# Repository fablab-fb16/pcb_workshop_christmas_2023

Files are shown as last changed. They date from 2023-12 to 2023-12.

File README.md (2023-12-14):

# Blinky Christmas Tree Ball - Soldering Kit

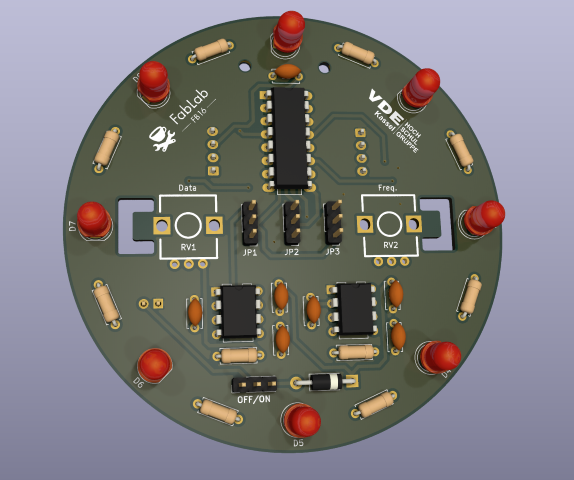
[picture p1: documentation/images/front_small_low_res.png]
PCB Front Side


Designed by Stefan Kablowski, Max Lindemann, Janos Föth.

Soldering workshop kindly sponsored by VDE Bezirksverein Kassel e. V.

## Quick Links

- [Detailed Build Instructions (EN)](/documentation/Build%20Instructions.md) / [Detaillierte Bauanleitung (DE)](/documentation/Build%20Instructions%20DE.md)
- [Assembly List](/documentation/Assembly%20List.md)
- [Usage Instructions](/documentation/Usage%20Instructions.md)
- [Schematics](/documentation/schematics.md)
- [Interactive BOM](https://fablab-fb16.github.io/pcb_workshop_christmas_2023/)

## Features
- Interactive: Adjustable blinking pattern and speed via two potentiometers
- Daisy-Chaining possible: Connect multiple christmas balls and push signals from master down the line for various patterns

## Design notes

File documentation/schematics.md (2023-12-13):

# Schematics

Two timers generate a square-wave signal (freqency independatly variable by potentiometers, see /notebooks folder for Jupyter notebook on frequency range calculation).

These two signals are used on data and clock input of shift register to create output patterns. Each output of the shift register is connected to one LED.

The Jumpers are used to select signal source and output source for daisy-chaining multiple boards. See [Usage Instructions](/documentation/Usage%20Instructions.md) for more info on this.

## Main Circuit
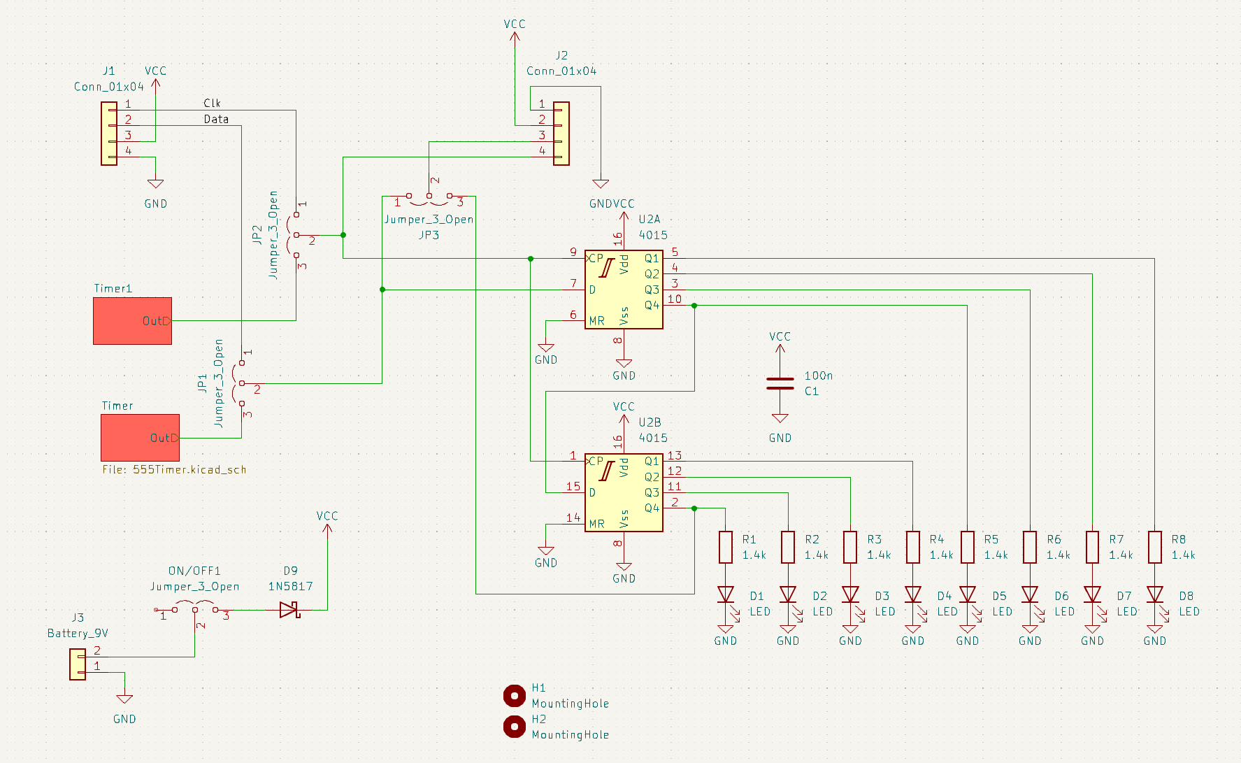
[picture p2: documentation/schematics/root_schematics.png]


## Timer (Data)
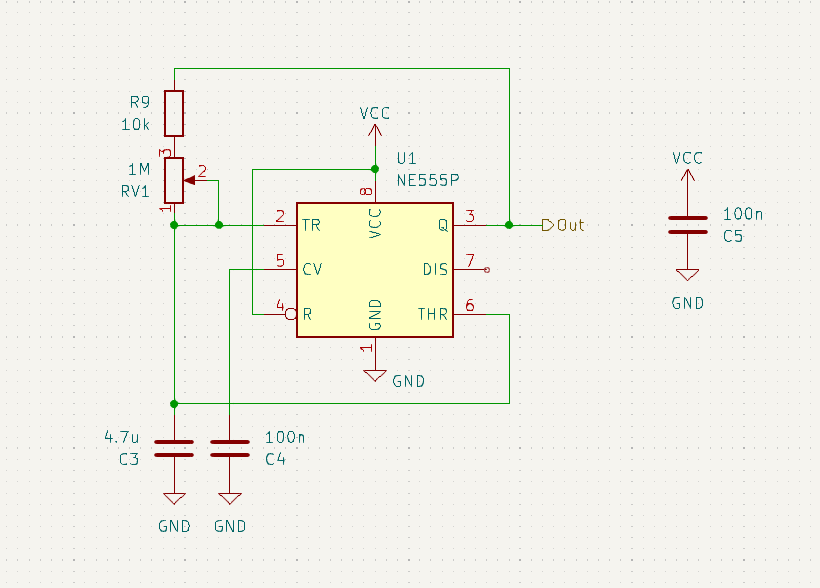
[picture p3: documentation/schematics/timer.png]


## Timer1 (Clock)
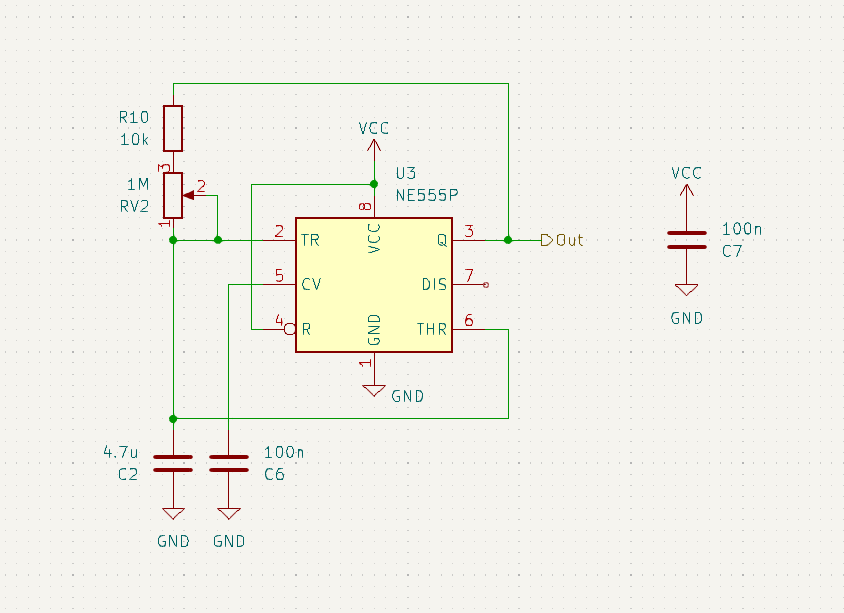
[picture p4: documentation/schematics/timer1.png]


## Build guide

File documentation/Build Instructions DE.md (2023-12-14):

# Bauanleitung (DE)

Dies ist eine detaillierte Anleitung mit Bildern. tl;dr -> [Assembly List](/documentation/Assembly%20List.md)

English Version: [Build Instructions](/documentation/Build%20Instructions.md)

## Allgemeine Infos
- Wenn du noch nie gelötet hast, schau dir die Anleitung an (auf Englisch, mit Bildern): [How to solder](/documentation/How%20to%20Solder.md)
- Alle Komponenten werden auf der Seite der Platine platziert, auf der die zugehörige Markierung des Bauteils ist. Gelötet wird immer auf der jeweils anderen Seite der Platine.
- Alle Bauteile haben eine Bezeichnung, welche in der Anleitung genannt wird, z.B. "R1" oder "D9". Diese Bezeichnung ist auch auf der Platine aufgedruckt. Dort muss das jeweilige Bauteil platziert werden.
- Manche Bauteile haben eine Orientierung -> Es ist wichtig, dass sie richtigherum eingebaut werden. Dies ist in der Anleitung in rot mit "Caution" gekennzeichnet. Einbaurichtung vor dem Löten nochmal prüfen. 
- Falls du Fragen hast: Am besten **vor** dem Löten fragen. 😉
- Have fun. 👩‍🏭👨‍🏭

## Anleitung
### Übersicht
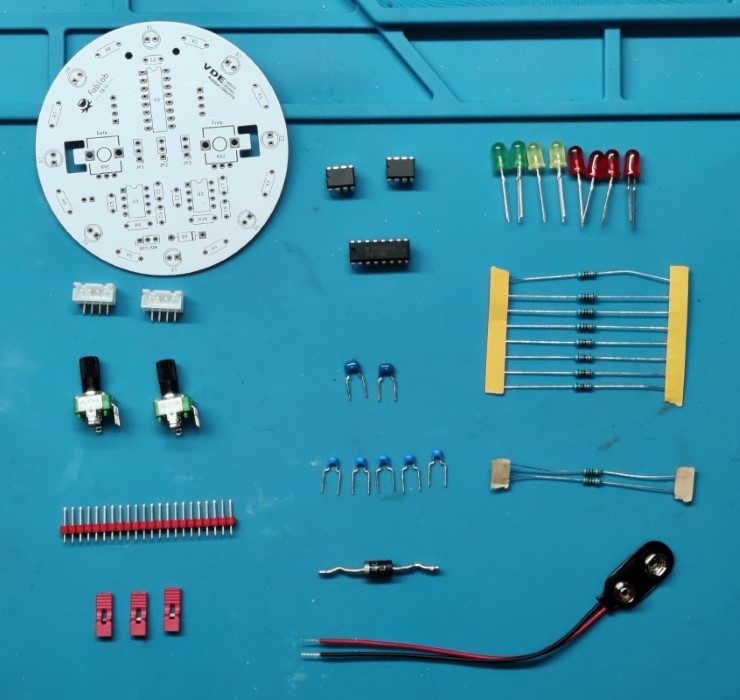
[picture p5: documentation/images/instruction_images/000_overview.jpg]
Overview

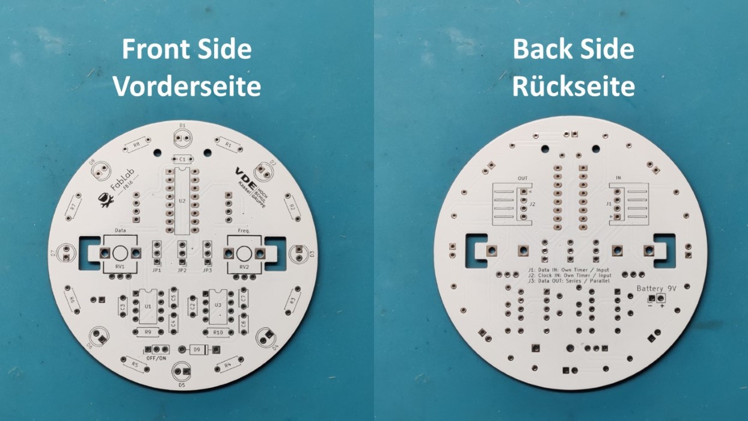
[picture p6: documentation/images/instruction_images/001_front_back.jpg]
Front-Back


### Erstes Bauteil - Diode: D9
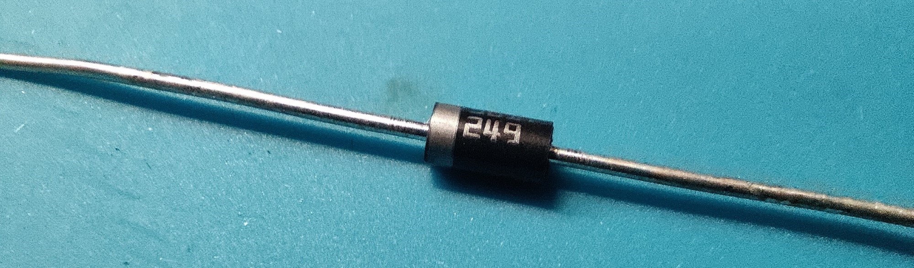
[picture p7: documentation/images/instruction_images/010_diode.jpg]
Diode


Biege die Beine der Diode (U-förmig)
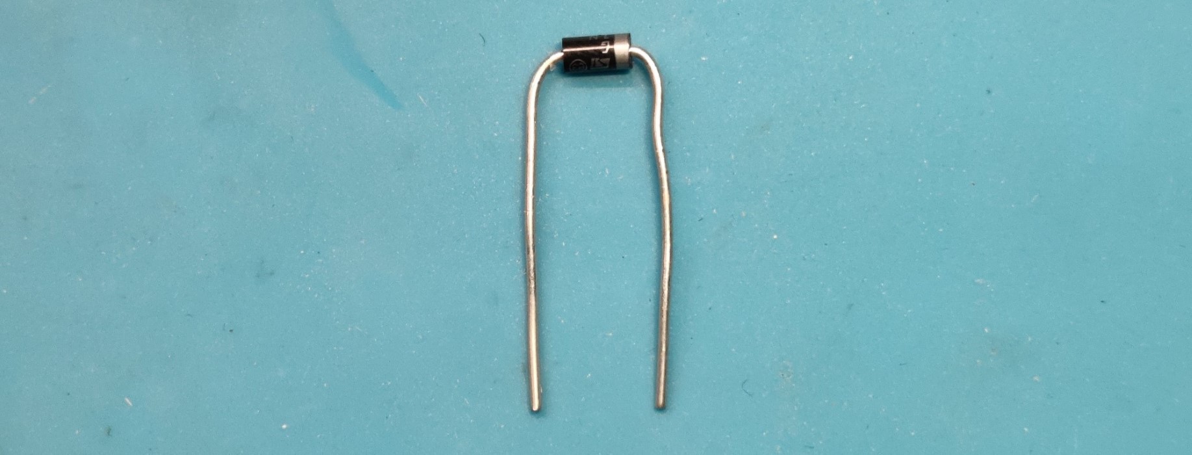
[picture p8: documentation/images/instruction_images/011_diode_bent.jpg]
Diode Bent


Stecke sie auf die Platine an der Position D9 (s. Bild unten).
> [!Caution]
> Beachte die Einbaurichtung: Silberner Ring nach rechts, wie auf der Platine markiert.

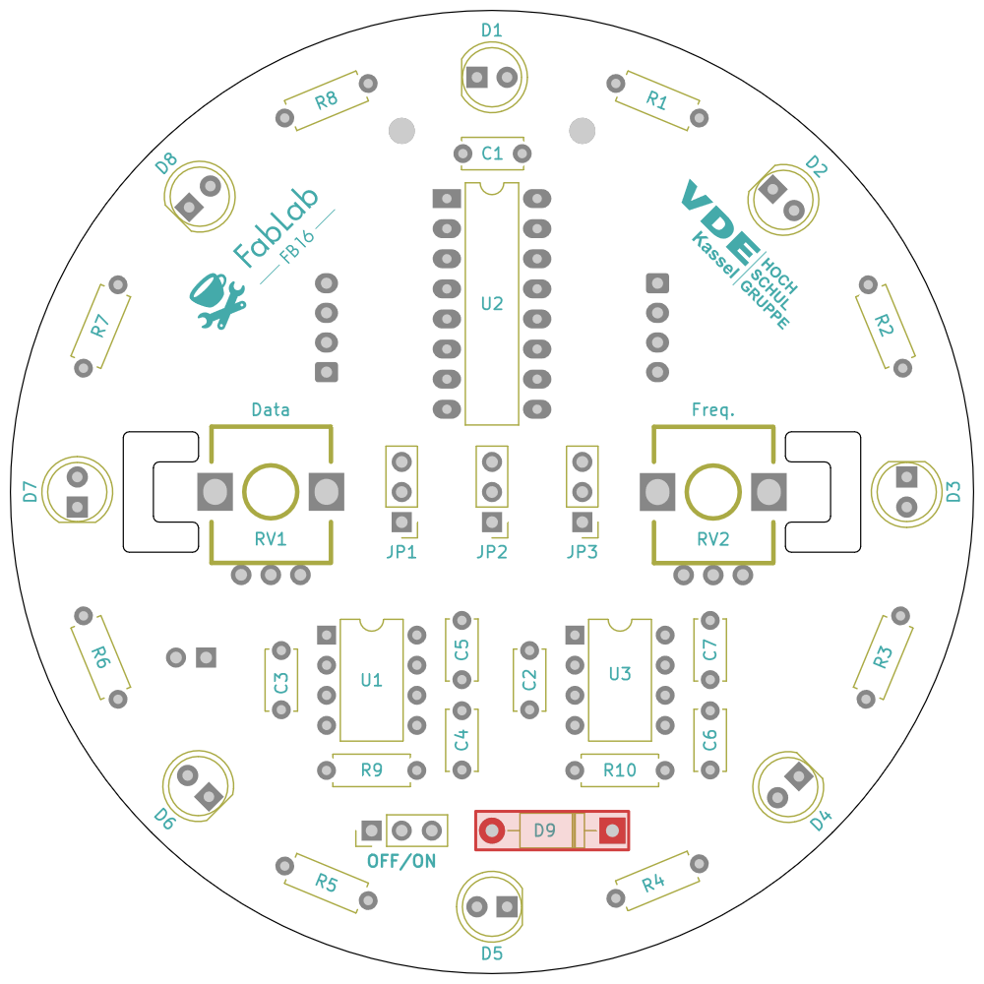
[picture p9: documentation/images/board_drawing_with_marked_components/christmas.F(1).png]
Diode on Board Drawing


Stecke die Diode bis ganz auf die Platine. Drehe die Platine um und löte die beiden Kontakte.
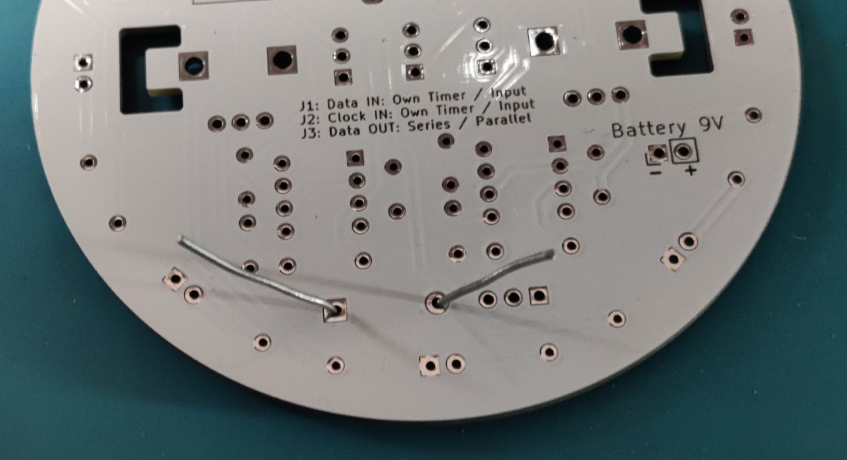
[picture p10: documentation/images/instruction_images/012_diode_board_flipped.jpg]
Diode Board Flipped

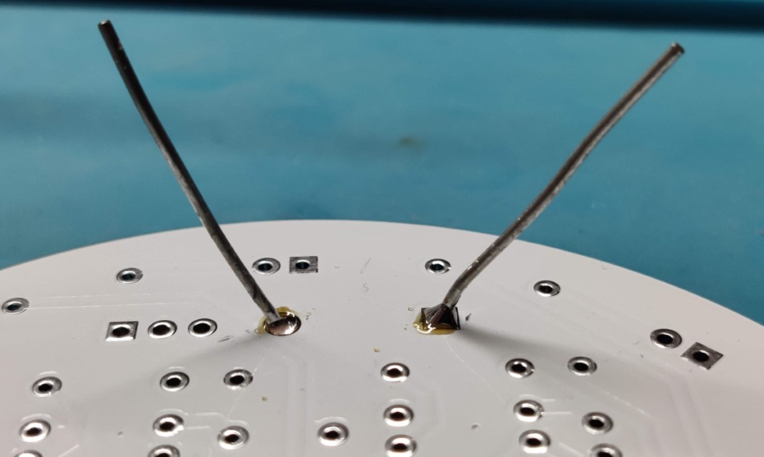
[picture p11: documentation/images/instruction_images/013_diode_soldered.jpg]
Diode Soldered


Schneide die Beine **oberhalb** der Lötstellen ab (nicht die Lötstelle selbst abschneiden).
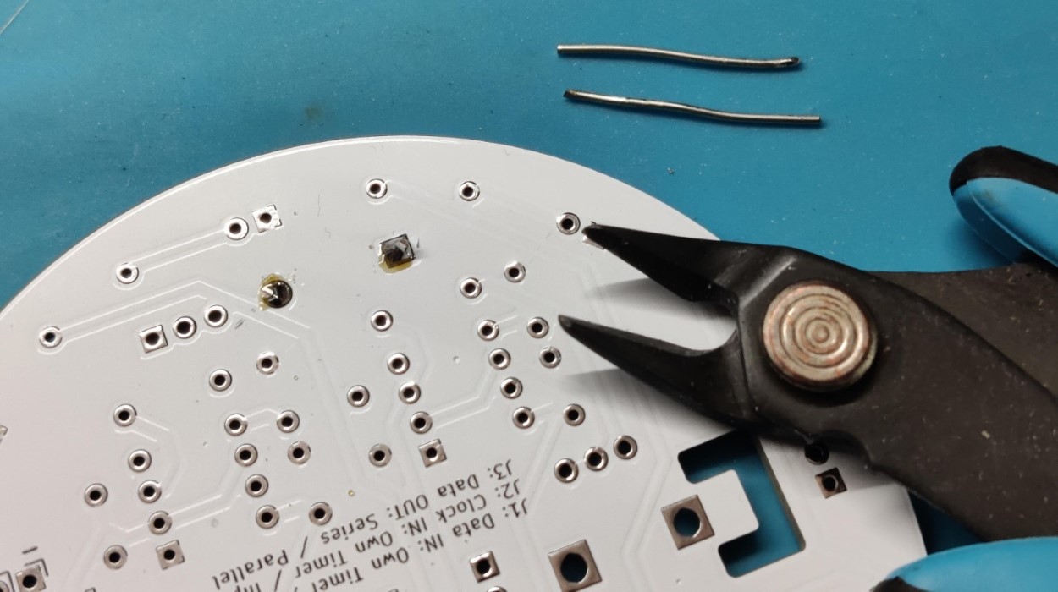
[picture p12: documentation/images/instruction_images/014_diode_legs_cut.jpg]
Diode Legs cut

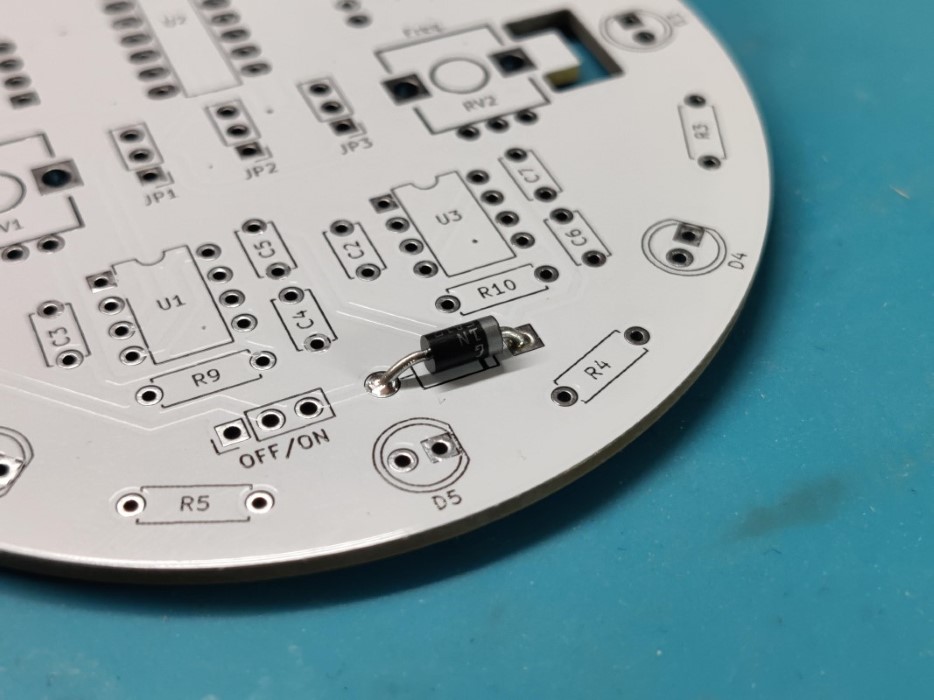
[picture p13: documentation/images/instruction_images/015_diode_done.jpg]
Diode Done


Erstes Bauteil geschafft.

### Widerstände: R1, R2, R3, R4, R5, R6, R7, R8
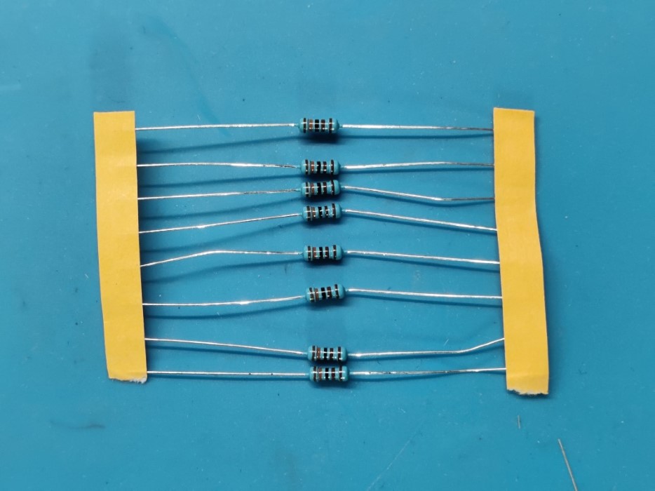
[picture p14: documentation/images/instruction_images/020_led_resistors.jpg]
LED Resistors 8x 1.3k

Identifiziere die Widerstände an ihren Farbringen: braun - orange - schwarz - braun - braun (Wert: 1.3k)

Biege die Beine (U-förmig), wie bei der Diode.

Stecke sie auf die Platine (diesmal ist die Einbaurichtung egal).
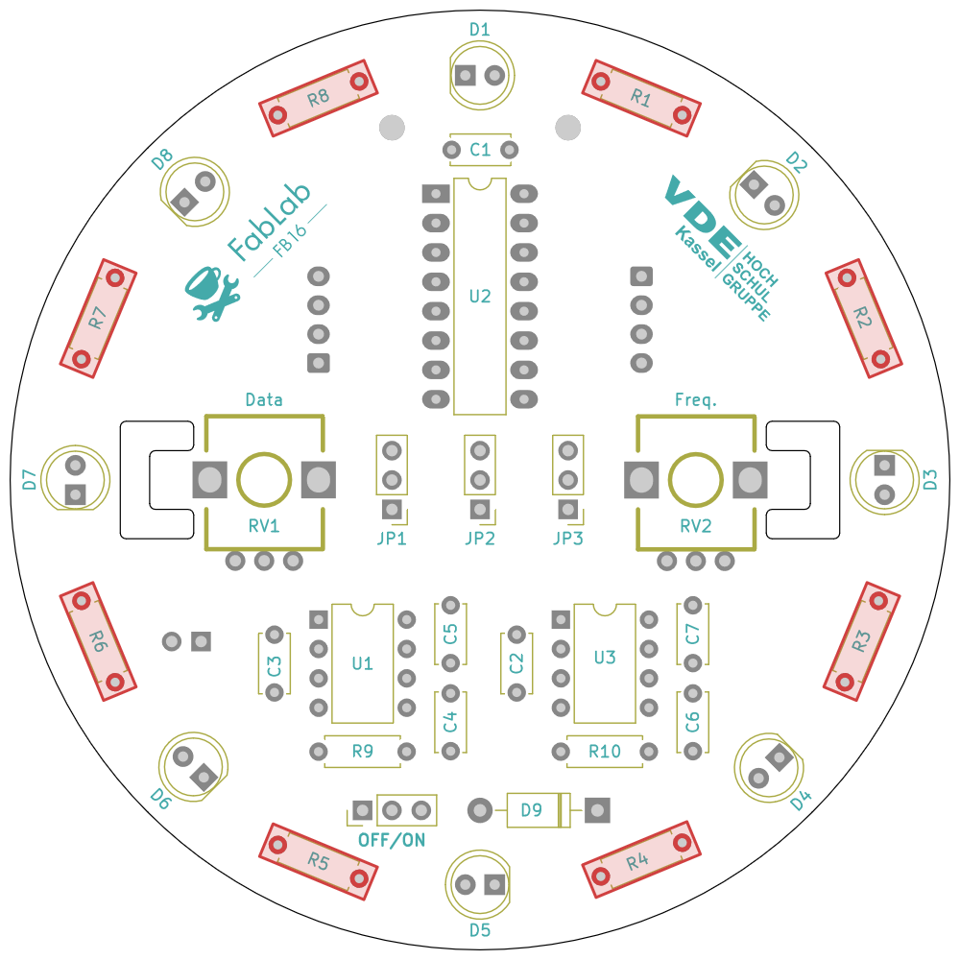
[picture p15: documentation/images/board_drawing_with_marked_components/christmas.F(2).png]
LED Resistors Board Drawing


Löten, Beine abschneiden, wiederholen bis alle Widerstände aufgelötet sind.

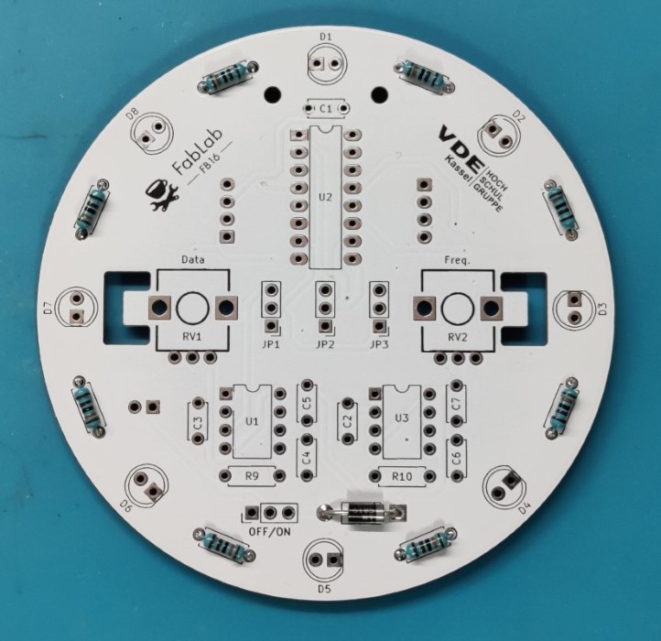
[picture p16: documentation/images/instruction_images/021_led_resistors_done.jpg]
LED Resistors Done


### Widerstände: R9, R10
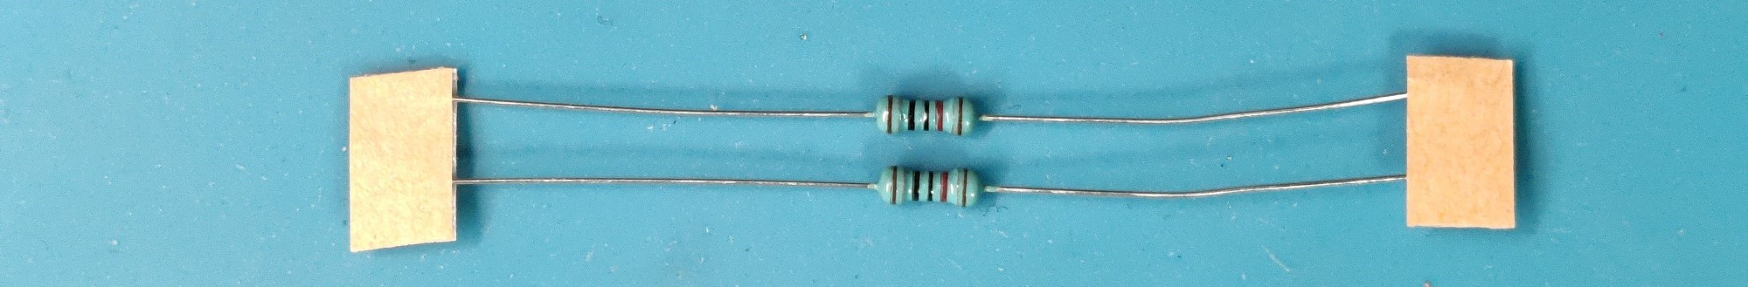
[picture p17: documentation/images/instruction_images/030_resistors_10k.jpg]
Resistors 2x 10k

Identifiziere die Widerstände an ihren Farbringen: braun - schwarz - schwarz - rot - braun (Wert: 10k)

Beine biegen, auf Platine stecken, löten, Beine abschneiden, wiederholen.
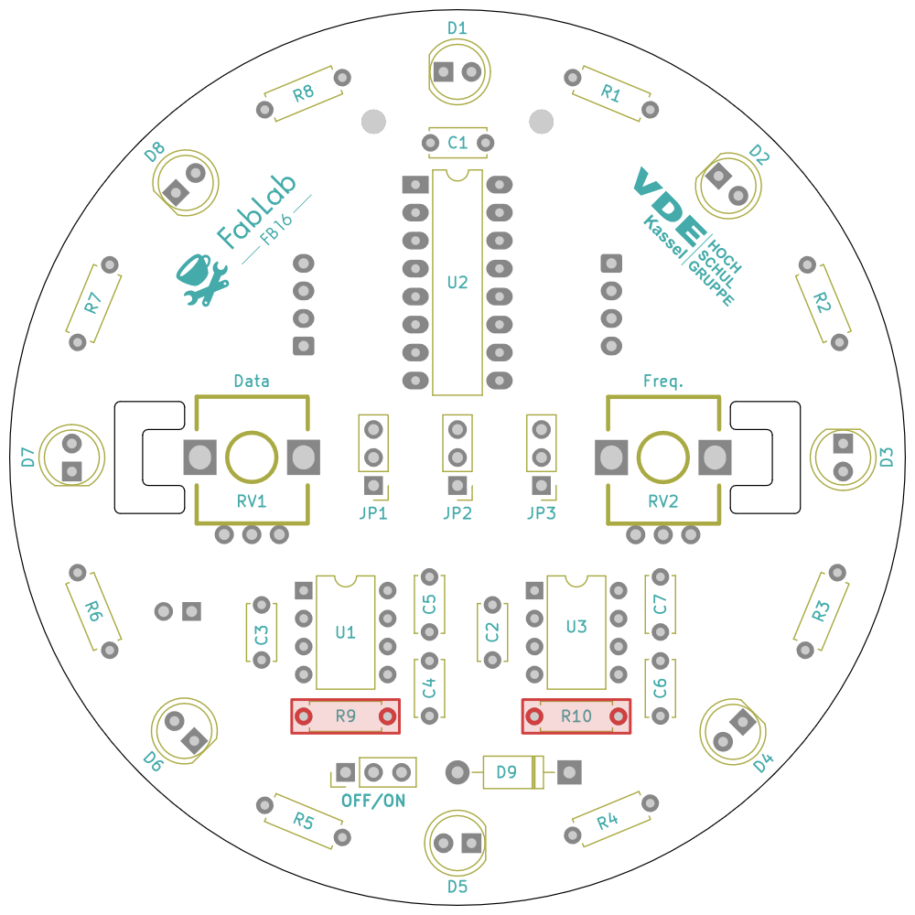
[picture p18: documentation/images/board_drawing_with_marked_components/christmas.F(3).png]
Resistors Board Drawing

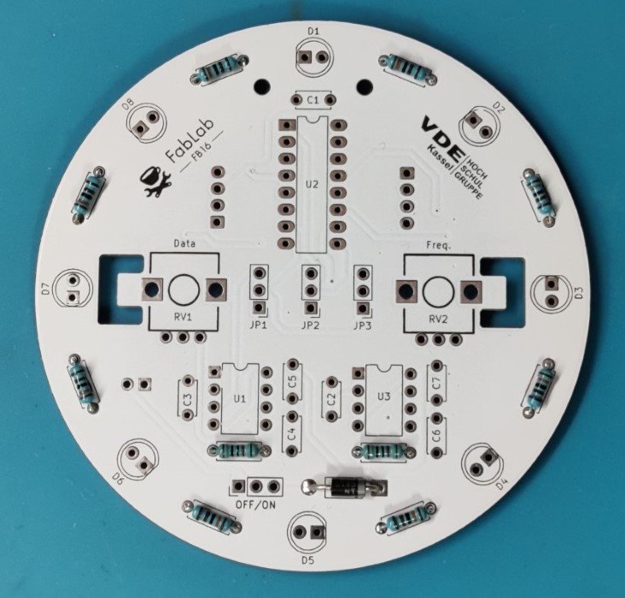
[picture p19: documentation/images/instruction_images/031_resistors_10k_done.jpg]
Resistors 2x 10k done


### Timer: U1, U3
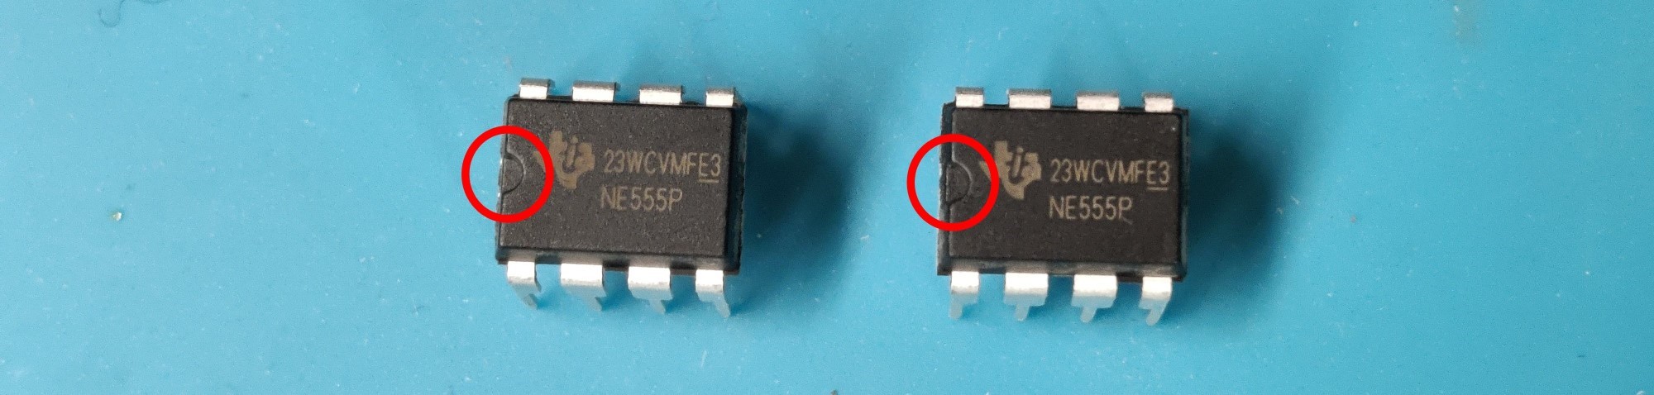
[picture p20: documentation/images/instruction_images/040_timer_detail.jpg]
Timers Detail

> [!Caution]
> Beachte die Einbaurichtung! Kleine Einkerbung nach oben.

Aufstecken, alle Beinchen löten. Verfahre mit allen weiteren Bauteilen so.

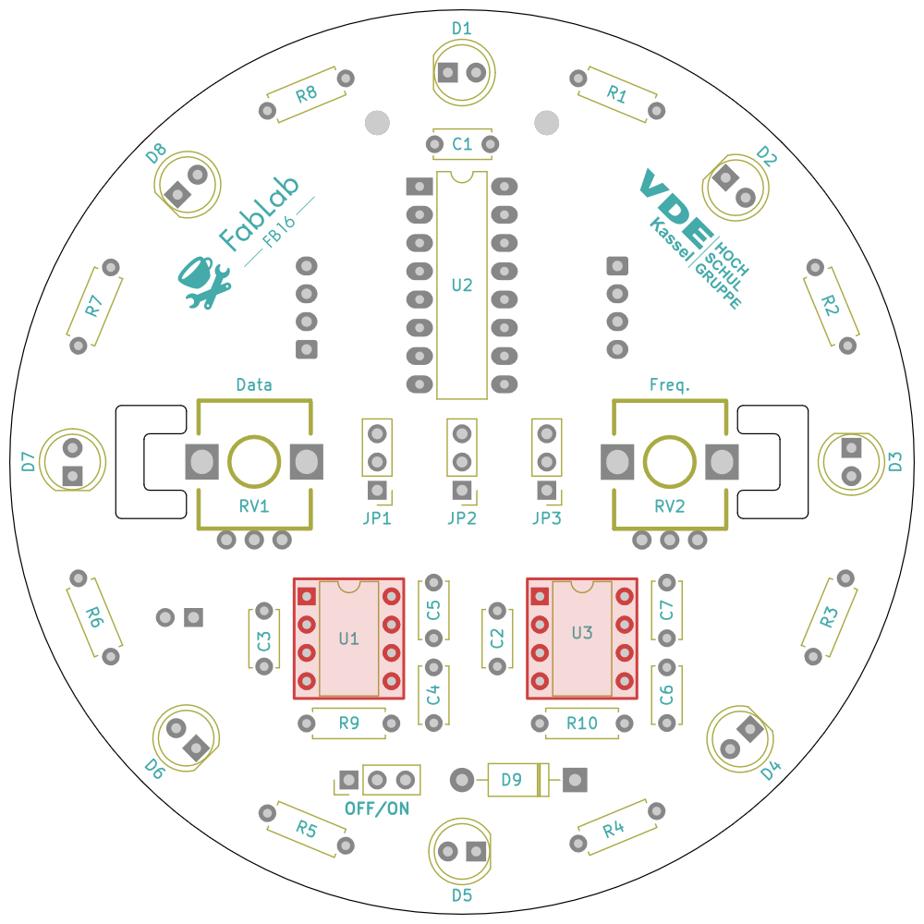
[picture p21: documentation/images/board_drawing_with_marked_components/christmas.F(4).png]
Timers Board Drawing

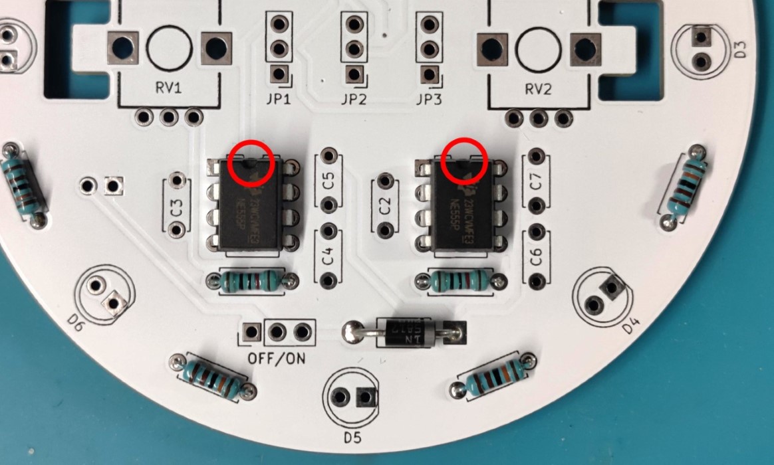
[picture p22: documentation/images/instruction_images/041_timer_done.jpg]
Timers done


### Schieberegister: U2
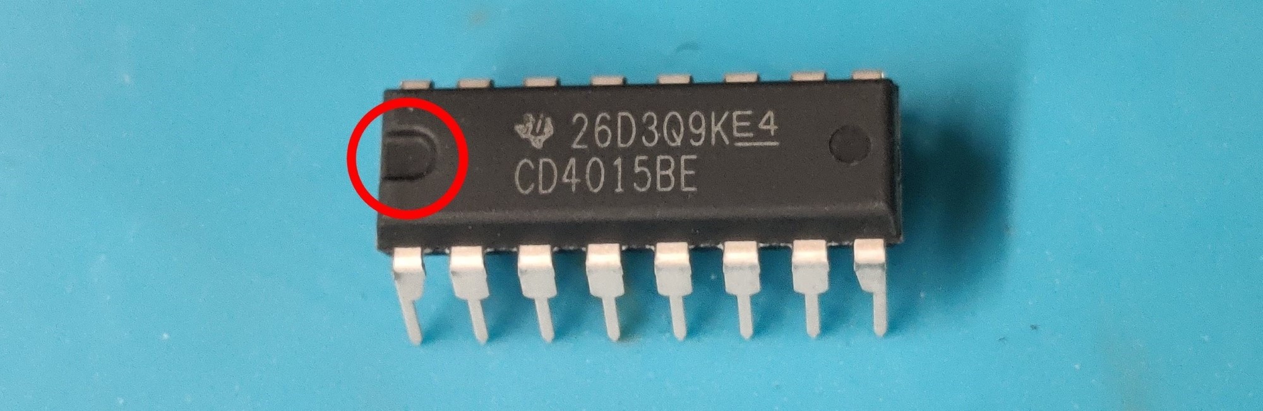
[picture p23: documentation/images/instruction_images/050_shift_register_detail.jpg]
Shift register Detail

> [!Caution]
> Beachte die Einbaurichtung! Kleine Einkerbung nach oben.

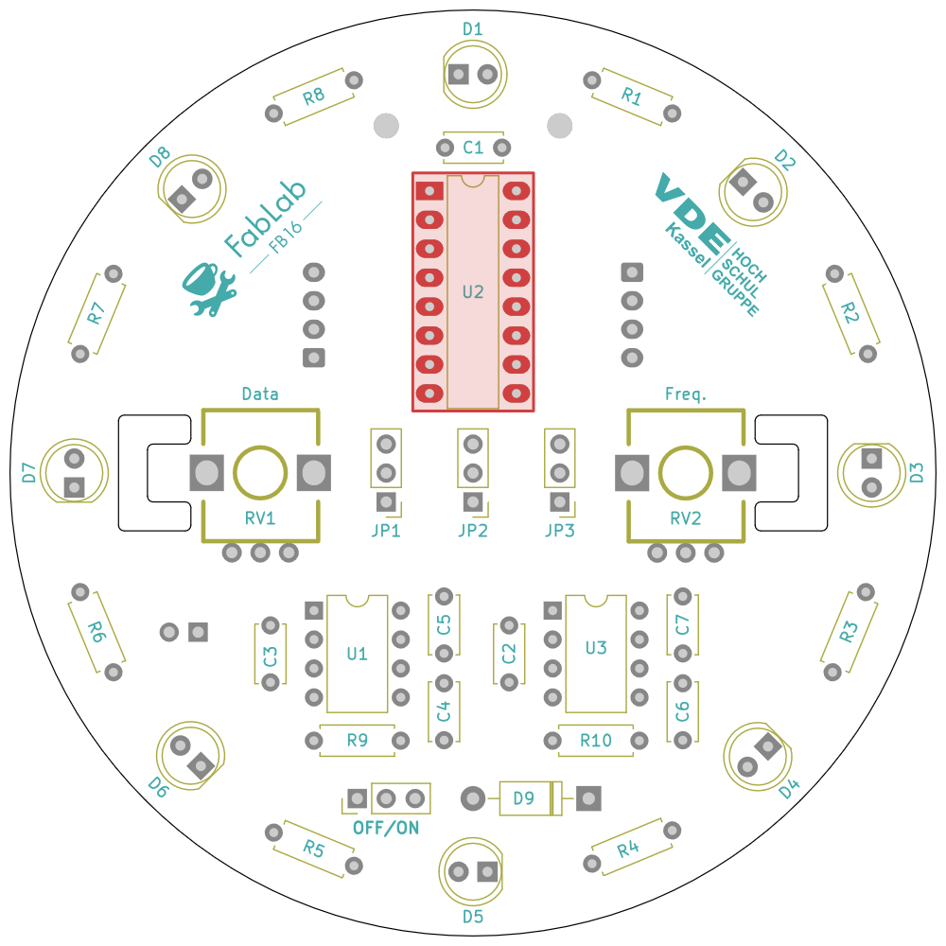
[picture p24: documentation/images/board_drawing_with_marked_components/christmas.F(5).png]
Shift register Board Drawing

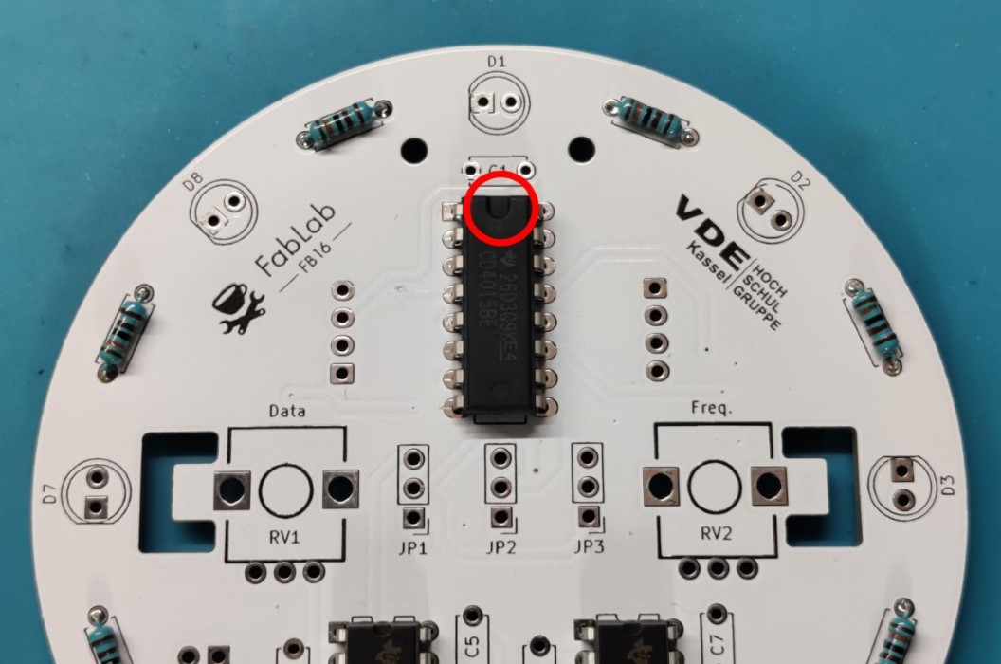
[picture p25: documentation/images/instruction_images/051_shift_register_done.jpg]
Shift register done


### Kondensatoren: C1, C4, C5, C6, C7
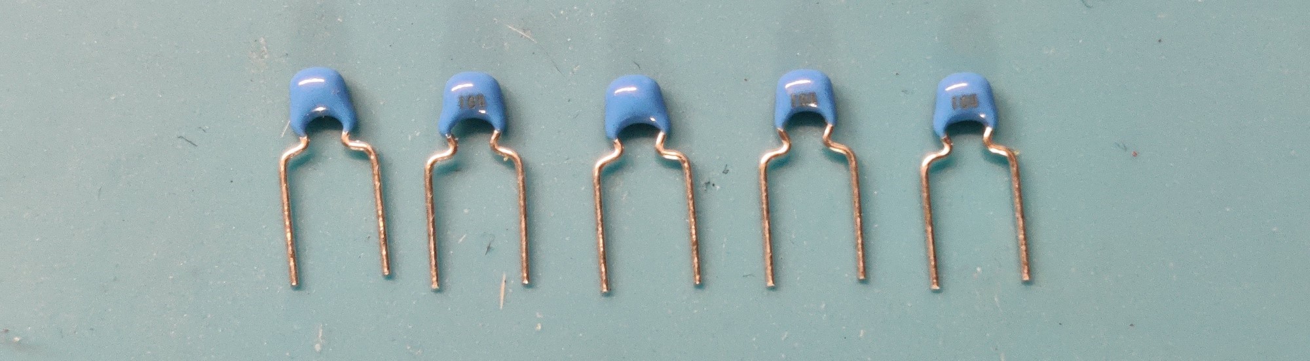
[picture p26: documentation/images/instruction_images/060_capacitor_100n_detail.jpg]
Capacitors 100nF Detail


> [!Caution]
> Achtung, es gibt Verschiedene! Hier brauchst du die Kleineren mit dem Aufdruck "104" (Wert: 100nF).

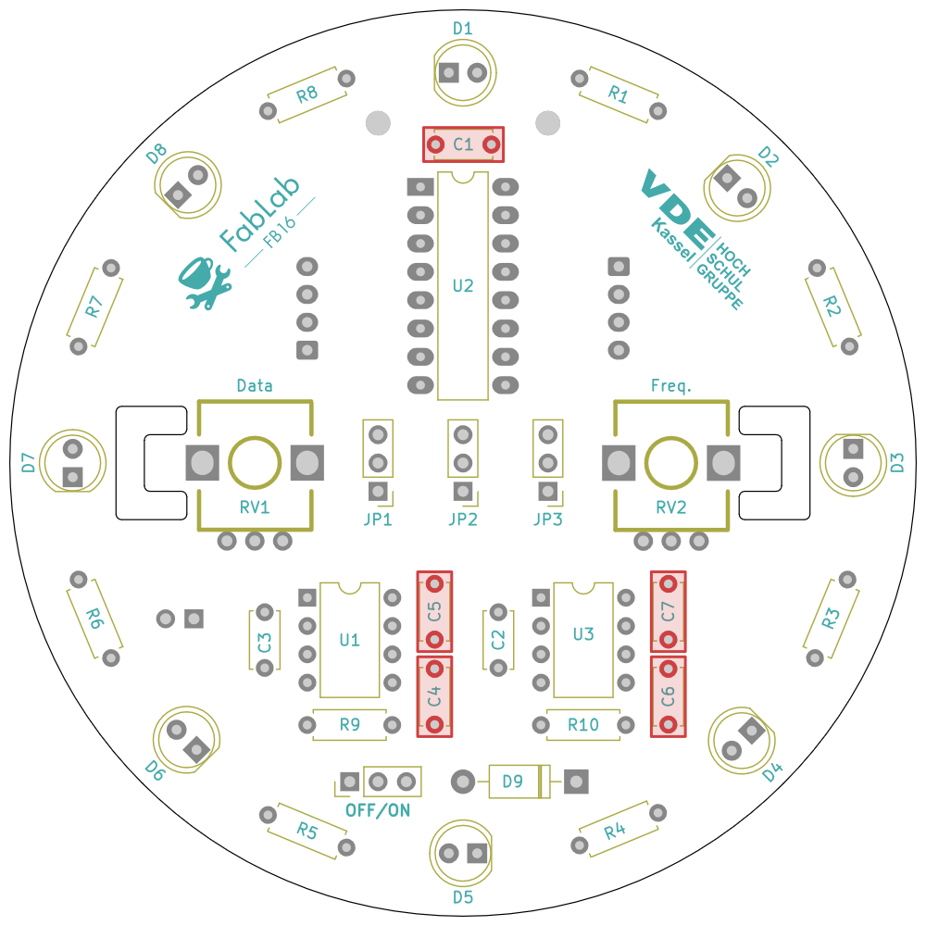
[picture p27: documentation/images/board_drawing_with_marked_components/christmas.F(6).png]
Capacitors 100nF Board Drawing

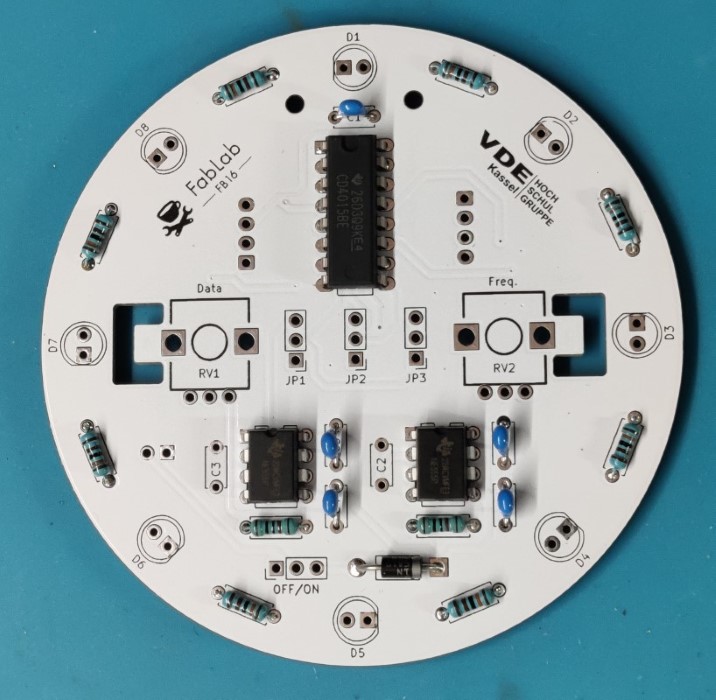
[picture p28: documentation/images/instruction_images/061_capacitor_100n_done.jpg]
Capacitors 100nF done


### Kondensatoren: C2, C3
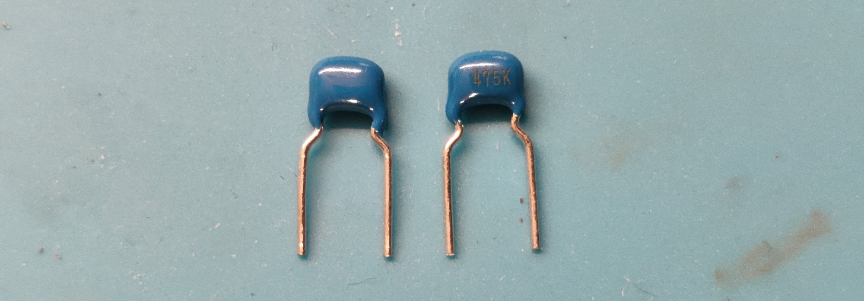
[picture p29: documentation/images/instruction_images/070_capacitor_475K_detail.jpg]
Capacitors 4.7uF Detail


> [!Caution]
> Achtung, es gibt Verschiedene! Hier brauchst du die Größeren mit dem Aufdruck "475K" (Wert: 4.7uF).

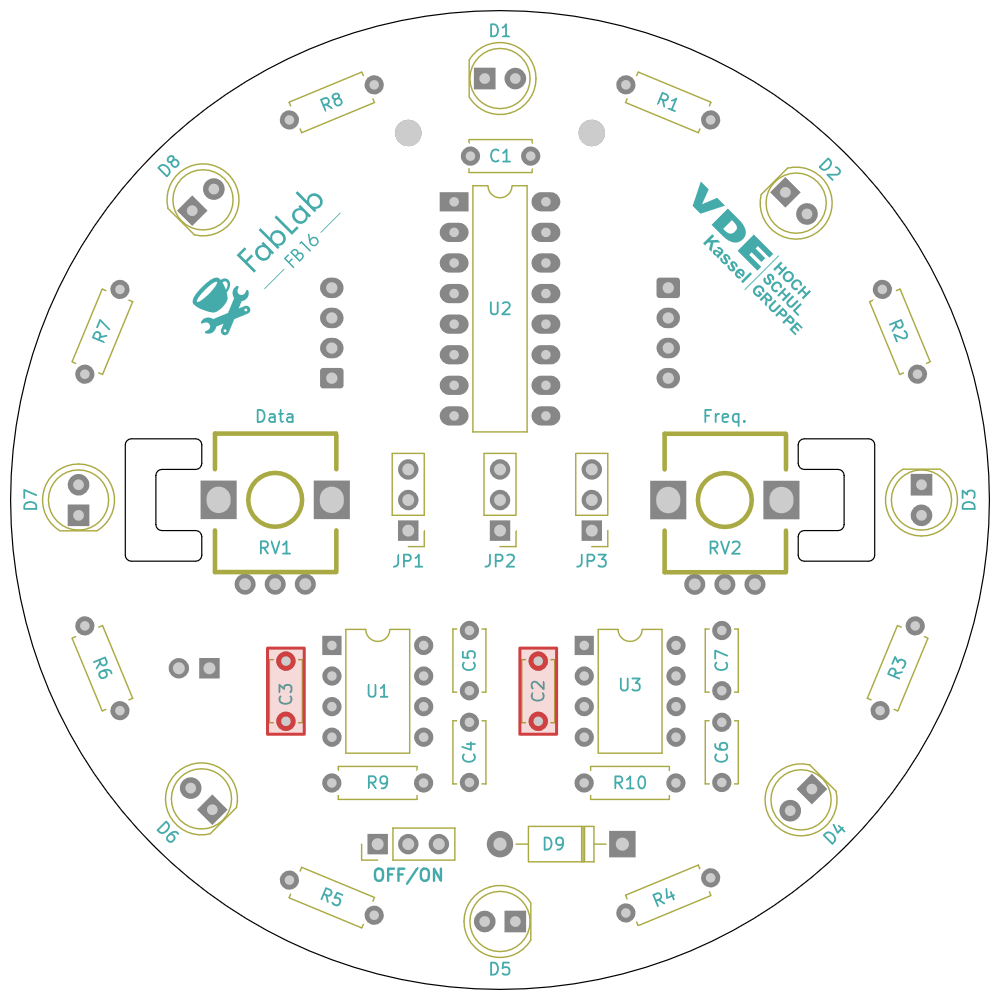
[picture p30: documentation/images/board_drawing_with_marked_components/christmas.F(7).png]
Capacitors 4.7uF Board Drawing

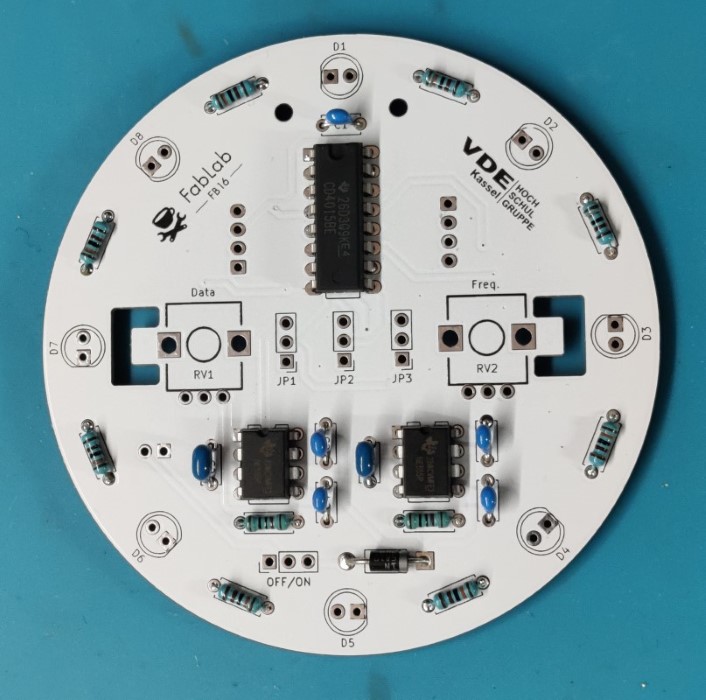
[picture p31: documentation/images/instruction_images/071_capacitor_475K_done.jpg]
Capacitors 4.7uF done


### LEDs: D1, D2, D3, D4, D5, D6, D7, D8
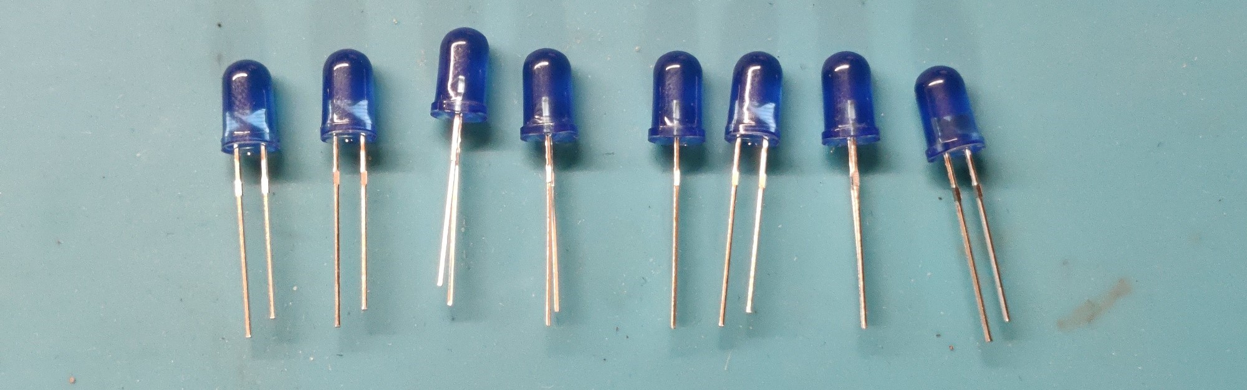
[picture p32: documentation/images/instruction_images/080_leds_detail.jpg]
LEDs Detail

Mische die verschiedenen Farben, wie du magst.
> [!Caution]
> Beachte die Einbaurichtung! Kurzes Bein in das Loch mit dem quadratischen Lötpad (s. Bild).

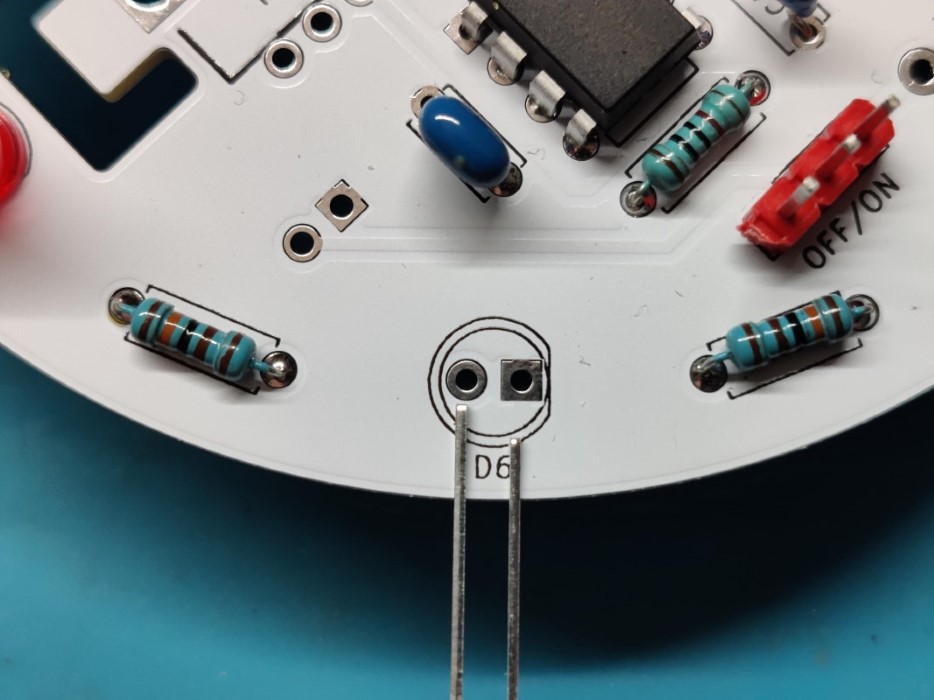
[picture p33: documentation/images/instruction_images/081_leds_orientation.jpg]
LEDs Detail

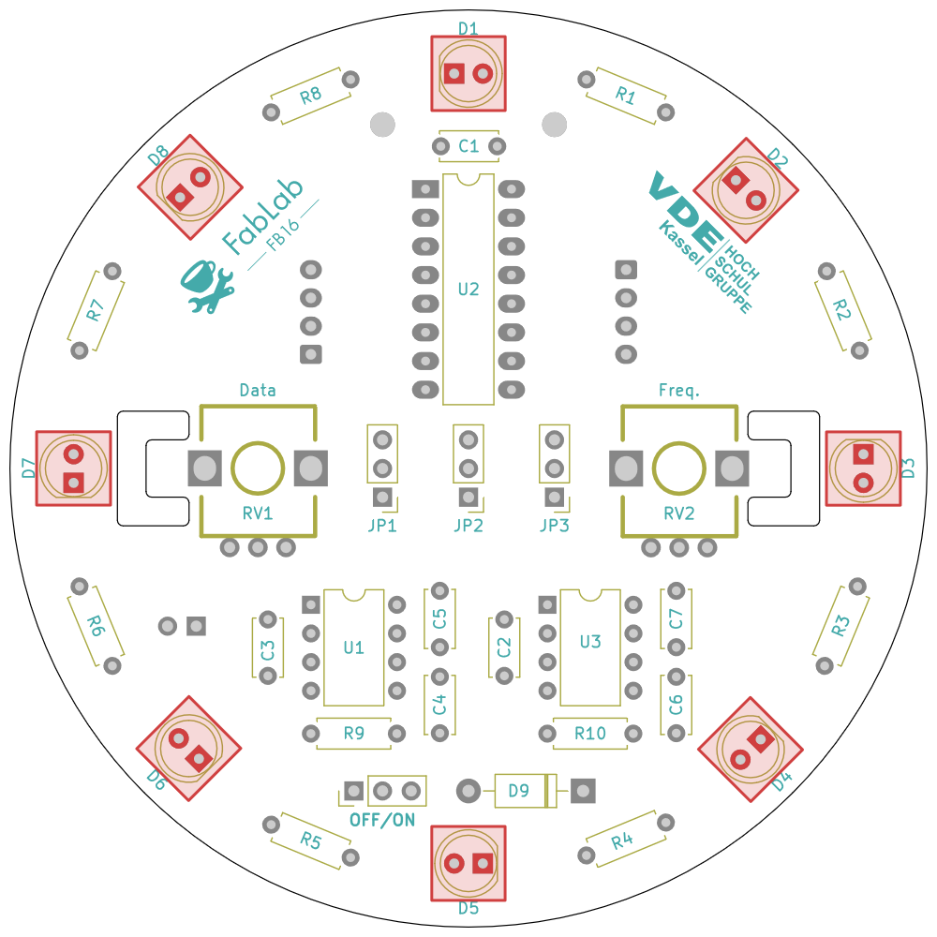
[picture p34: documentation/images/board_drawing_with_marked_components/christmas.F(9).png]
LEDs Board Drawing

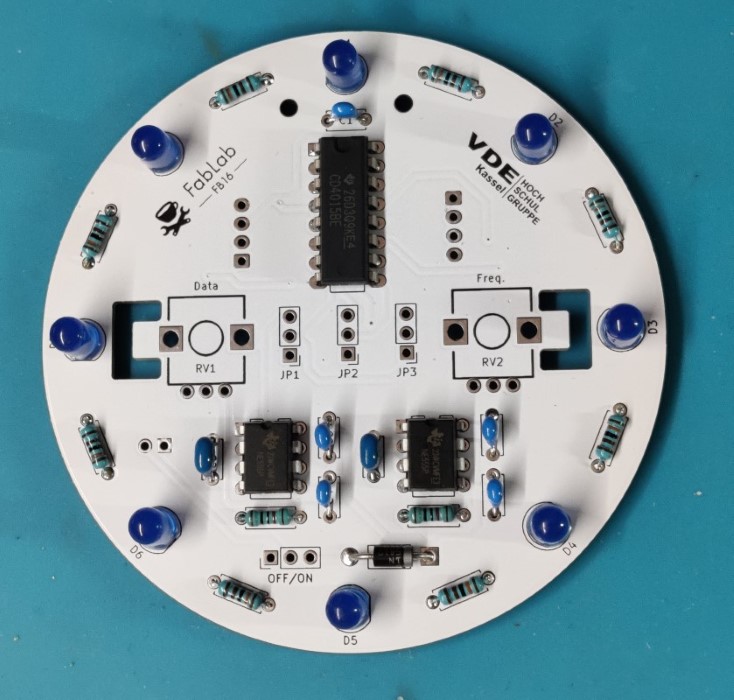
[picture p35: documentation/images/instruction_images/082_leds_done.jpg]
LEDs Done


### Jumper: JP1, JP2, JP3, ON/OFF
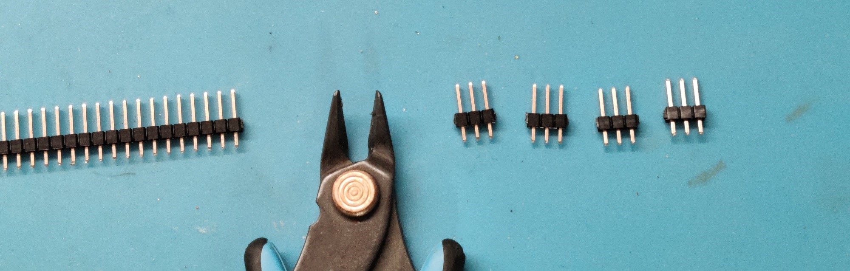
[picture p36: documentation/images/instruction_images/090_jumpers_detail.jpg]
Jumpers Detail

Schneide sie mit dem Seitenschneider in 4 Stücke á 3 Pins (s. Bild). Bring den Rest gerne zur Bauteil-Ausgabe zurück.

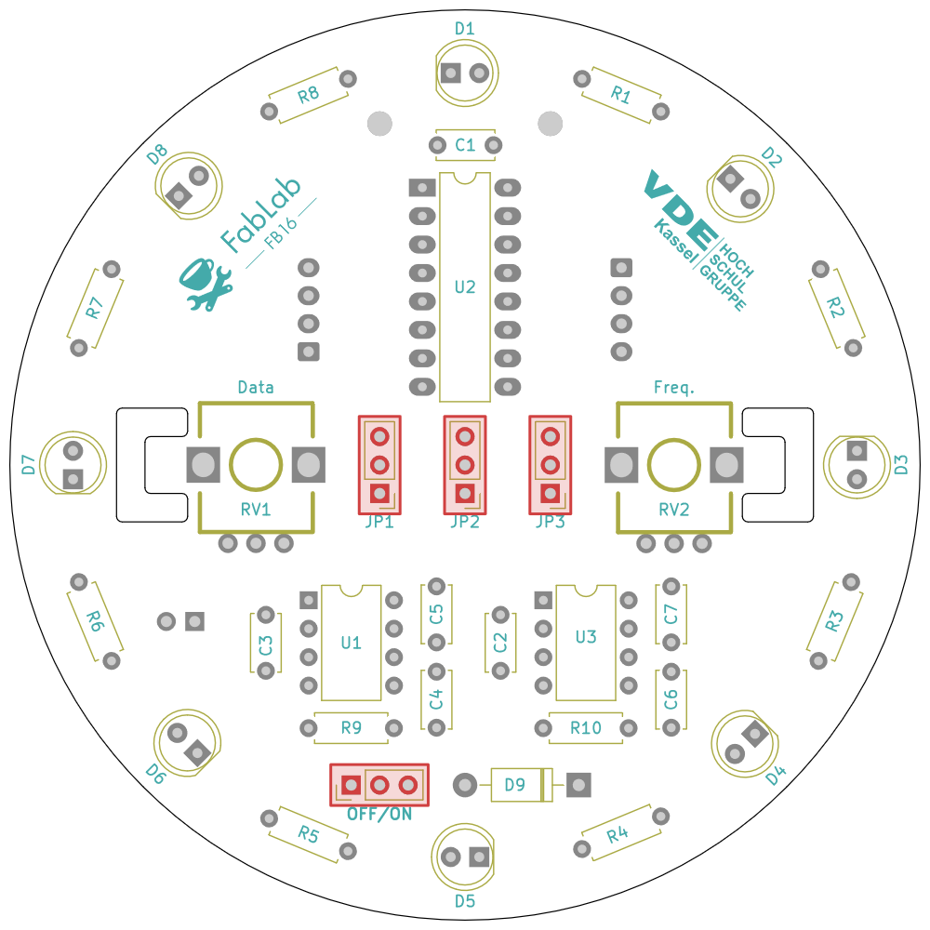
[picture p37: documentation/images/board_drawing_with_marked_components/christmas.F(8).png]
Jumpers Board Drawing

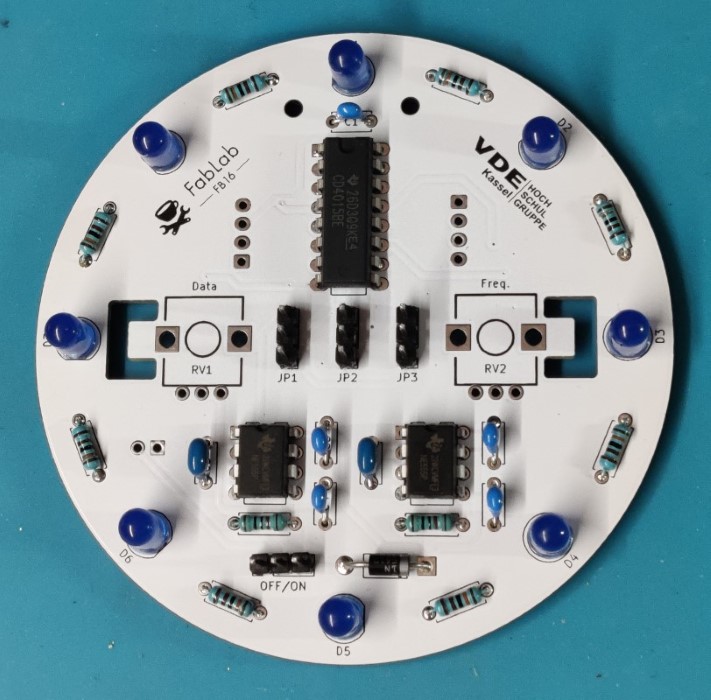
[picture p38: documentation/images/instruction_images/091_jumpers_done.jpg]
Jumpers Done


### Potentiometer: RV1, RV2
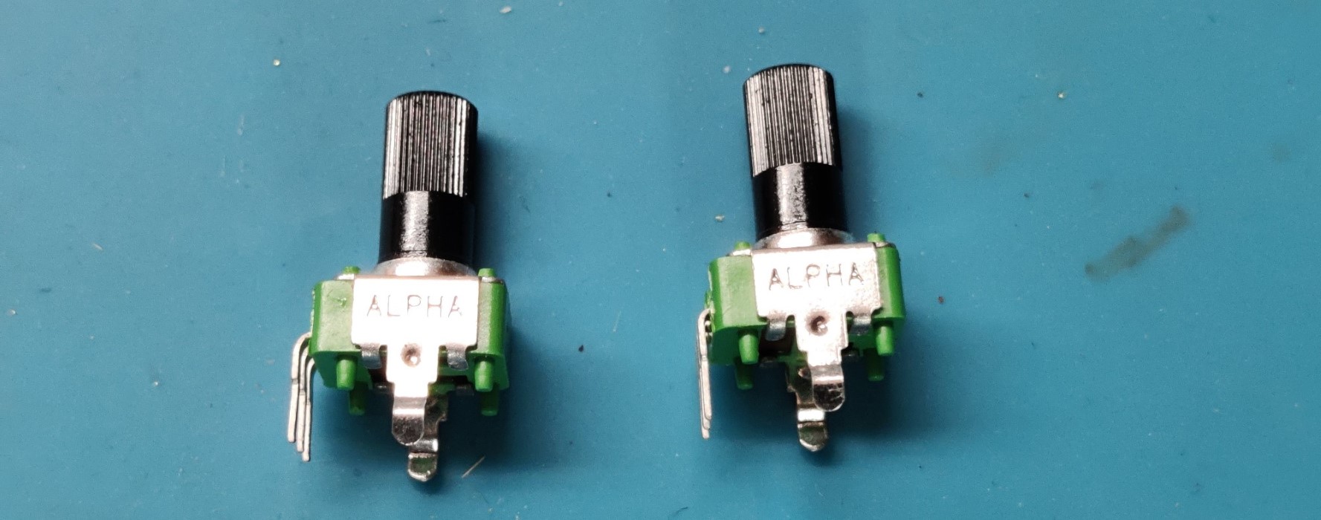
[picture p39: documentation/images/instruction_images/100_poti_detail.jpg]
Potentiometers Detail

Die Potentiometer "klipsen" auf die Platine - das braucht etwas Kraft (aber keine Gewalt, falls es nicht geht frag uns nach Hilfe). Löte dann alle Kontakte, auch die großen.

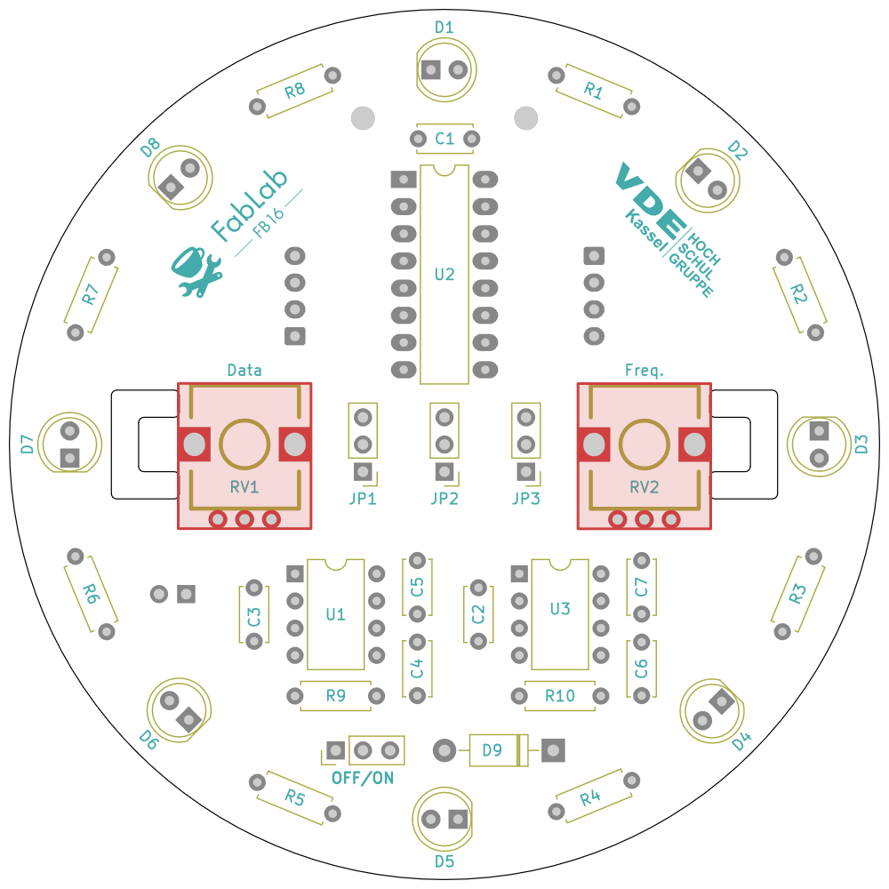
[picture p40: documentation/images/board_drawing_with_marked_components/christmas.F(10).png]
Potentiometers Board Drawing

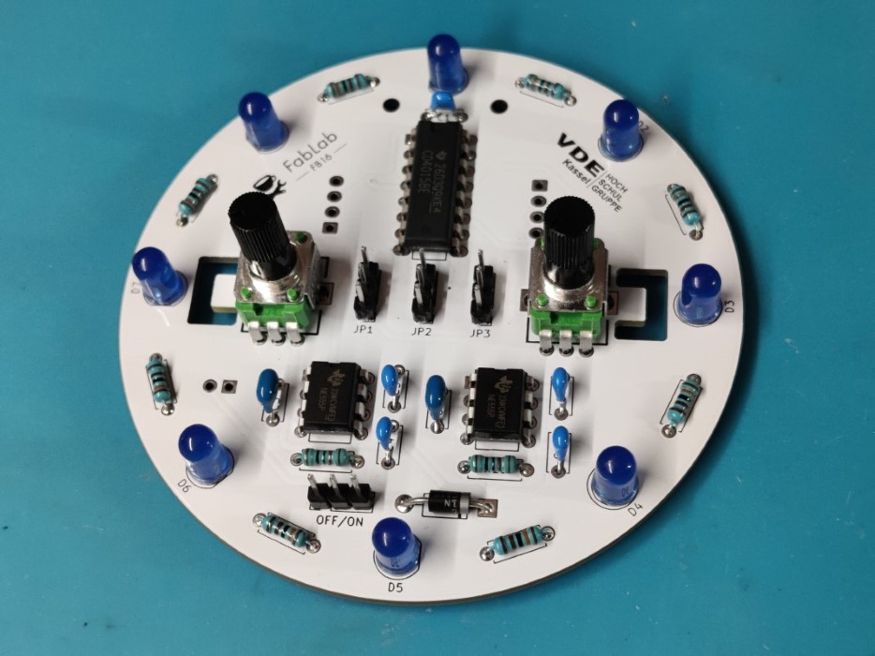
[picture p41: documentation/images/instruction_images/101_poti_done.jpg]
Potentiometers Done


### Batterie-Anschluss: Battery_9V
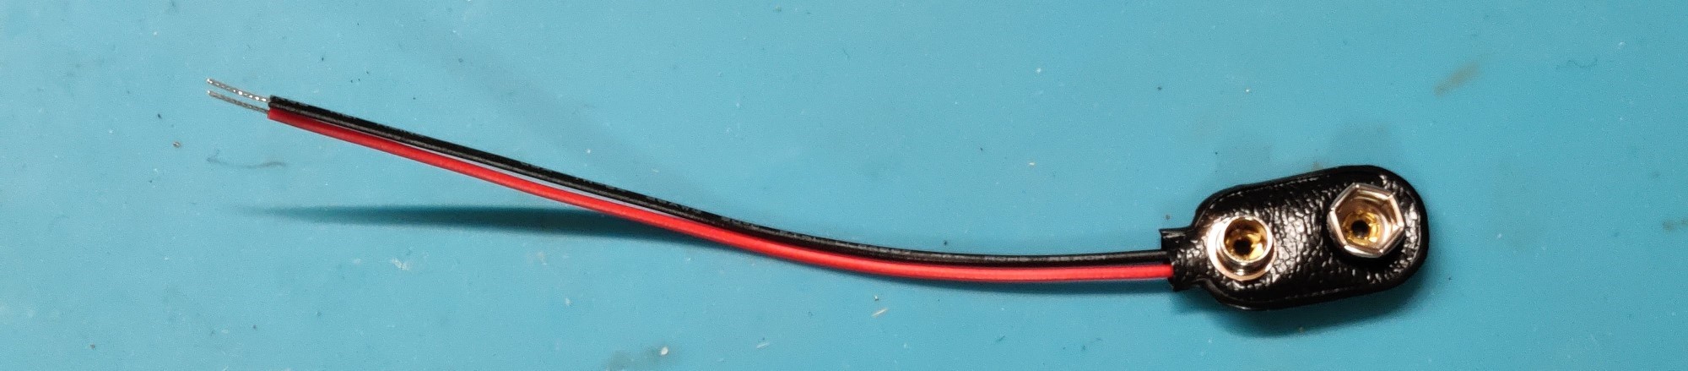
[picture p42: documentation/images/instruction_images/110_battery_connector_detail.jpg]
Battery Connector Detail

> [!Caution]
> Dieses Teil gehört auf der Rückseite der Platine und wird auf der Vorderseite gelötet.
> Beachte die Einbaurichtung: Rotes Kabel an **+** , Schwarzes Kabel an **-**

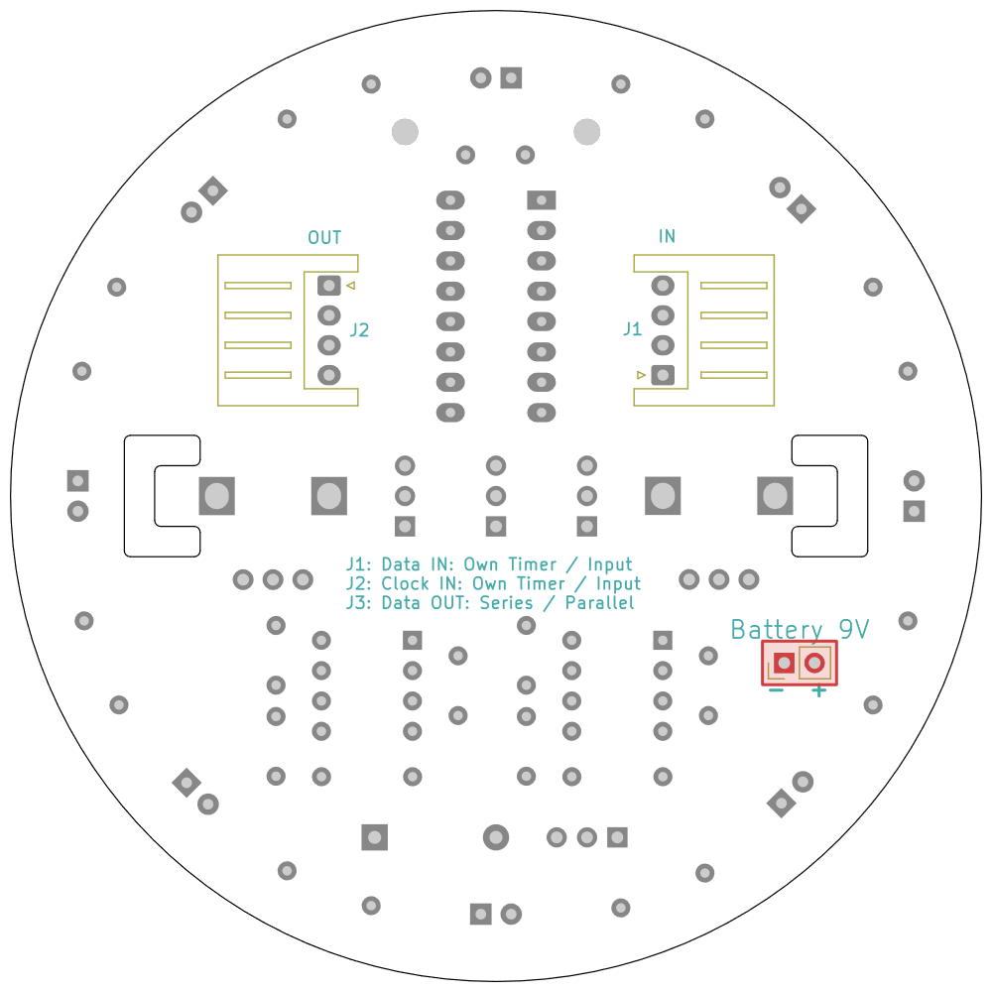
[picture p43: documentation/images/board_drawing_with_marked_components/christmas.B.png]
Battery Connector Board Drawing

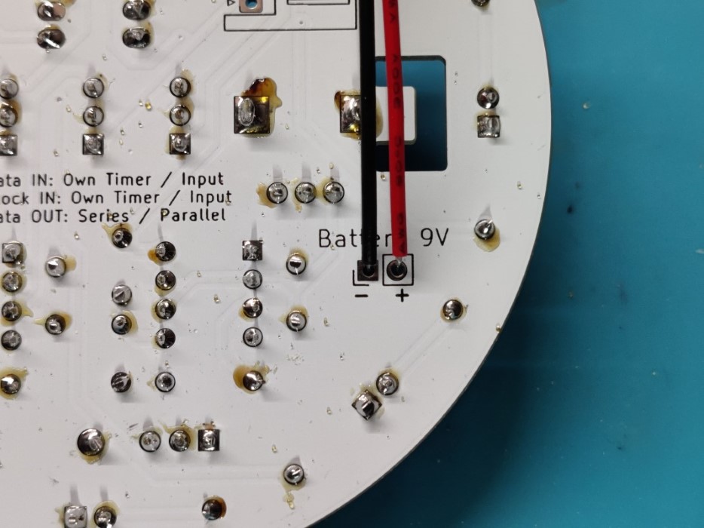
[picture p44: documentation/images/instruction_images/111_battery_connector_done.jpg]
Battery Connector Done


### Kabel Buchsen: J1, J2
Wire Connectors Detail
> [!Caution]
> Dieses Teil gehört auf der Rückseite der Platine und wird auf der Vorderseite gelötet.
> Beachte die Einbaurichtung! Siehe Bilder.

Wire Connectors Board Drawing
Wire Connectors Done

**Glückwunsch, du hast das Löten geschafft. Es sind nur noch wenige Schritte nötig, bis du fertig bist.**

### Stecke die Jumper auf
Jumper Connectors Detail
Stecke die vier Jumper wie folgt auf (ebenfalls im unteren Bild zu sehen)
- JP1, JP2, JP3: obere Position
- OFF/ON: linke Position (OFF)

Jumper Connectors Done

### Befestige die Batterie und schließe sie an
Wickele die Batterie in Isolierband / Klebeband (damit sie keinen Kurschluss auf der Platine verursacht).
Battery Detail

Nutze ein Gummiband um die Batterie auf der Rückseite der Platine zu befestigen (s. Bilder).
Schließe die Batterie an das Kabel an (Richtung beachten).

Battery Done

### Knote einen Faden zum Aufhängen an (optional)
String Done

### Geschafft! Stecke den Jumper "OFF/ON" in die rechte Position (ON) und los geht's. ✨
Wenn du alles richtig gemacht hast, beginnen die LEDs zu blinken.
Mit den zwei Potentiometern kannst du das Muster und die Geschwindigkeit des Blinkens verstellen.

Für mehr Infos zu Benutzung, siehe [Usage Instructions](/documentation/Usage%20Instructions.md) (auf Englisch).

Finally Done

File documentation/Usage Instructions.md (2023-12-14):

# Usage Instructions
The Christmas Ball has two Potentiometers and four Jumpers for control.



## Stand-Alone use
- JP1, JP2, JP3: upper position
- OFF/ON: right position
- use both potentiometers to control blinking pattern and speed; just play around

## Details for daisy-chaining
Connect multiple christmas balls via the connectors on the back and set the jumpers as you want - description below:
### Jumpers
| Name | Description | Upper Position | Lower Position |
| --- | --- | --- | --- |
| JP1 | Shift Register Data Source  | use on-board timer signal | use signal from INPUT connector |
| JP2 | Shift Register Clock Source | use on-board timer signal | use signal from INPUT connector |
| JP3 | Data Output | Series Connection: send shift register output to OUT | Parallel Connection: send data timer output to OUT |
| OFF/ON | Turn power on/off | - | - |

### Potentiometers

- Left (RV1): Control Data Timer signal frequency
- Right (RV2): Control Clock Timer signal frequency

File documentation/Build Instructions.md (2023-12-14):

# Build Instructions (EN)

This is a detailed guide with images. tl;dr -> [Assembly List](/documentation/Assembly%20List.md)

## General Info
- If you don't know how to solder, look at [How to solder](/documentation/How%20to%20Solder.md)
- All components are placed on the side of the board, where their marking is. Soldering is done on the opposite side.
- All components have a label e.g. "R1" or "D9" which tells you, where to put the component on the board.
- Some components are directional -> Orientation matters for them. This is denoted with a red "Caution" tag, because it's important. Double-check orientation **before** soldering.
- If you are not sure about something: Ask before soldering 😉
- Have fun. 👩‍🏭👨‍🏭

## Build the Christmas Tree Ball
### Overview
Overview
Front-Back

### First Component - Diode: D9
Diode

Bend the legs of the Diode (U-shape)
Diode Bent

Place it on the board at position D9. Push it all the way down.
> [!Caution]
> For this part the orientation is important! Silver ring to the right.

Diode on Board Drawing

Flip the board and solder the two connections.
Diode Board Flipped
Diode Soldered

Cut the excess component legs above the solder joint.
Diode Legs cut
Diode Done

### Resistors: R1, R2, R3, R4, R5, R6, R7, R8
LED Resistors 8x 1.3k
Identify them by Color Code: brown - orange - black - brown - brown (Value: 1.3k)

Bend the legs (U-shape)

Place on board (orientation doesn't matter).
LED Resistors Board Drawing

Solder, cut legs, repeat.

LED Resistors Done

### Resistors: R9, R10
Resistors 2x 10k
Identify them by Color Code: brown - black - black - red - brown (Value: 10k)

Bend legs, place on board, solder, cut legs, repeat.
Resistors Board Drawing
Resistors 2x 10k done

### Timers: U1, U3
Timers Detail
> [!Caution]
> Orientation is important! Little notch to the top.

Timers Board Drawing
Timers done

### Shift register: U2
Shift register Detail
> [!Caution]
> Orientation is important! Little notch to the top.

Shift register Board Drawing
Shift register done

### Capacitors: C1, C4, C5, C6, C7
Capacitors 100nF Detail
Identify them: They are the smaller ones with "104" printed on.  (Value: 100nF)

Capacitors 100nF Board Drawing
Capacitors 100nF done

### Capacitors: C2, C3
Capacitors 4.7uF Detail
Identify them: They are the larger ones with "475K" printed on. (Value: 4.7uF)

Capacitors 4.7uF Board Drawing
Capacitors 4.7uF done

### LEDs: D1, D2, D3, D4, D5, D6, D7, D8
LEDs Detail
Mix colors as you want.
> [!Caution]
> Orientation is important! Shorter leg into the hole with the squared pad. (see image)

LEDs Detail
LEDs Board Drawing
LEDs Done

### Jumpers: JP1, JP2, JP3, ON/OFF
Jumpers Detail
Cut them with the cutter to 4 pieces á 3 Pins (see image).

Jumpers Board Drawing
Jumpers Done

### Potentiometers: RV1, RV2
Potentiometers Detail
They snap to the board; use gentle force to put them on. Solder all contacts, the large ones too.

Potentiometers Board Drawing
Potentiometers Done

### Battery Connector: Battery_9V
Battery Connector Detail
> [!Caution]
> This is placed on the back side and soldered on the front side.
> Orientation is important: Red wire to **+** , black wire to **-**

Battery Connector Board Drawing
Battery Connector Done

### Wire Connectors: J1, J2
Wire Connectors Detail
> [!Caution]
> This is placed on the back side and soldered on the front side.
> Orientation is important! See images.

Wire Connectors Board Drawing
Wire Connectors Done

**Congratulations, you're done with soldering. Only a few steps are left.**

### Place Jumpers
Jumper Connectors Detail
Place the four Jumper connectors (also shown in the below image)
- JP1, JP2, JP3: on the top position
- OFF/ON: on the left position (OFF)

Jumper Connectors Done

### Mount and connect battery
Wrap the battery in tape (for insulation)
Battery Detail

Use the rubber band to attach the battery to the back of the board (see images).
Connect the battery to the battery connector.

Battery Done

### Attach string (optional)
String Done

### You're done! Plug the Jumper "OFF/ON" to the right position (ON) and enjoy. ✨
Turn the two potentiometers to adjust the blinking pattern and speed.

For more information check the [Usage Instructions](/documentation/Usage%20Instructions.md).

Finally Done

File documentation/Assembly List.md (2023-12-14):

# Assembly List

Assemble in the listed order for the best experience.

Place components on the side of the PCB where the respective marking is, and solder on the opposite side.

| Reference on PCB | Component | Quantity | Notes |
| --- | --- | --- | --- |
| D9 | Diode (1N5817) | 1 | Orientation important! Silver ring to the right. |
| R1, R2, R3, R4, R5, R6, R7, R8 | Resistor (1.3k) | 8 | Color Code: brown - orange - black - brown - brown  |
| R9, R10 | Resistor (10k) | 2 | Color Code: brown - black - black - red - brown |
| U1, U3 | Timer (NE555P, DIP-8) | 2 | Orientation important! Notch to the top. |
| U2 | Shift Register (4015, DIP-16) | 1 | Orientation important! Notch to the top. |
| C1, C4, C5, C6, C7 | Capacitor (100nF, smaller ones) | 5 | |
| C2, C3 | Capacitor (4.7uF, larger ones)  | 2 | |
| JP1, JP2, JP3, ON/OFF | Jumpers (3 Pins, 2.54mm) | 4 | |
| D1, D2, D3, D4, D5, D6, D7, D8 | LEDs | 8 | Orientation important! Short leg to square pad. |
| RV1, RV2 | Potentiometers | 2 | |
| Battery_9V | Battery Cable (9V Block) | 1 | Place on back side. Red wire to + ; Black wire to - |
| J1, J2 | Cable Connector | 2 | Place on back side. |

After soldering all components, see [last steps in build instructions](/documentation/Build%20Instructions.md#place-jumpers) (from "Place Jumpers" onwards).

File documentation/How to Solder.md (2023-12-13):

# How to Solder - Short Instruction

1. Place component on the side of the board, where the marking is.
2. Flip the board.
3. Heat the joint (pad on the board and component leg) with the soldering iron for ~2 seconds.
4. Add solder to the joint. It's the right amount of solder if it forms a cone (see images below).
5. Remove the solder.
6. Remove the soldering iron.
7. Trim / cut the excess component leg.
8. Repeat.

[Guide with images](https://learn.adafruit.com/adafruit-guide-excellent-soldering)

[Short Instructional Video](https://youtu.be/UpVx4wGukRc?t=87)

# Image Instructions


[Image Source](https://circuitmess.com/blogs/resources/ringo-ch-3-time-to-get-makin-pg-1)

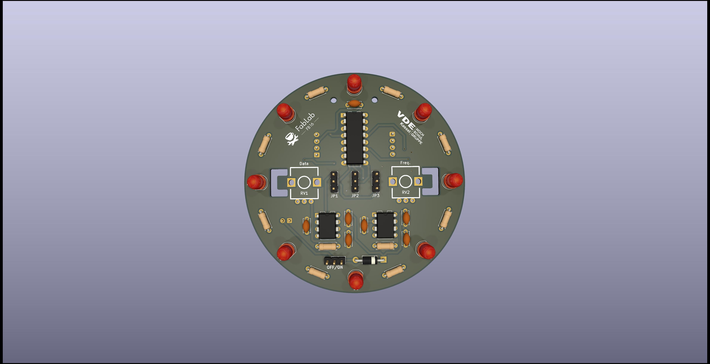
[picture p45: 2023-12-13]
documentation/images/front_usage_instructions.jpg

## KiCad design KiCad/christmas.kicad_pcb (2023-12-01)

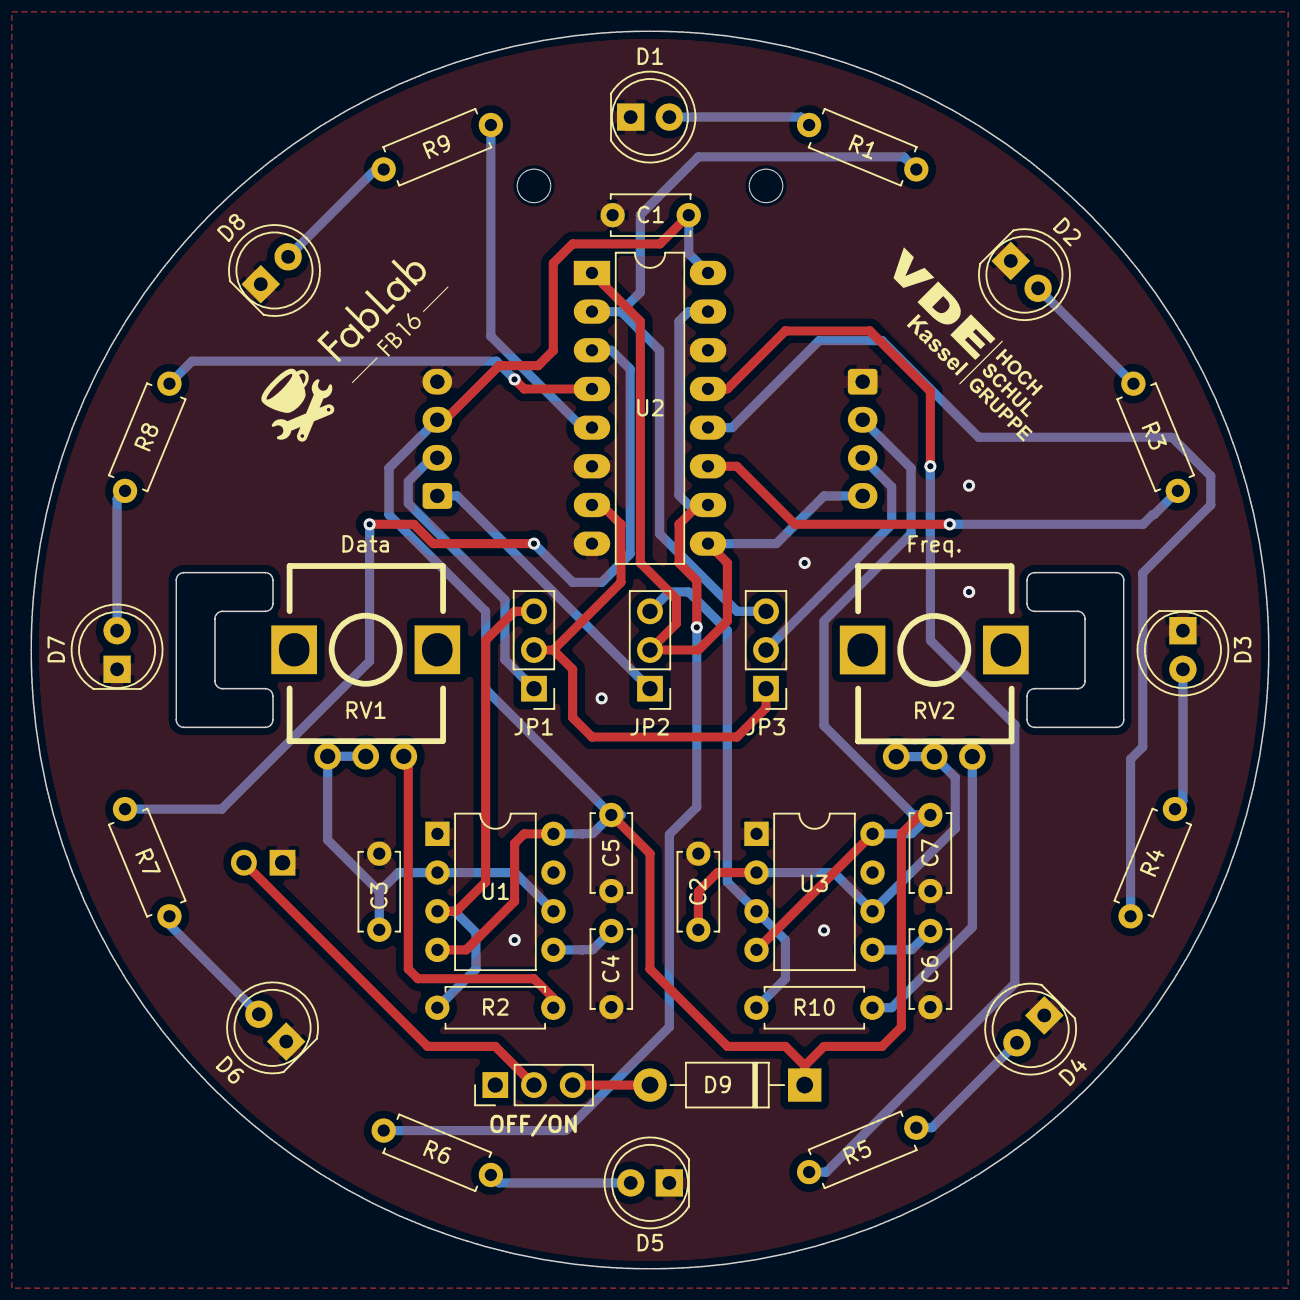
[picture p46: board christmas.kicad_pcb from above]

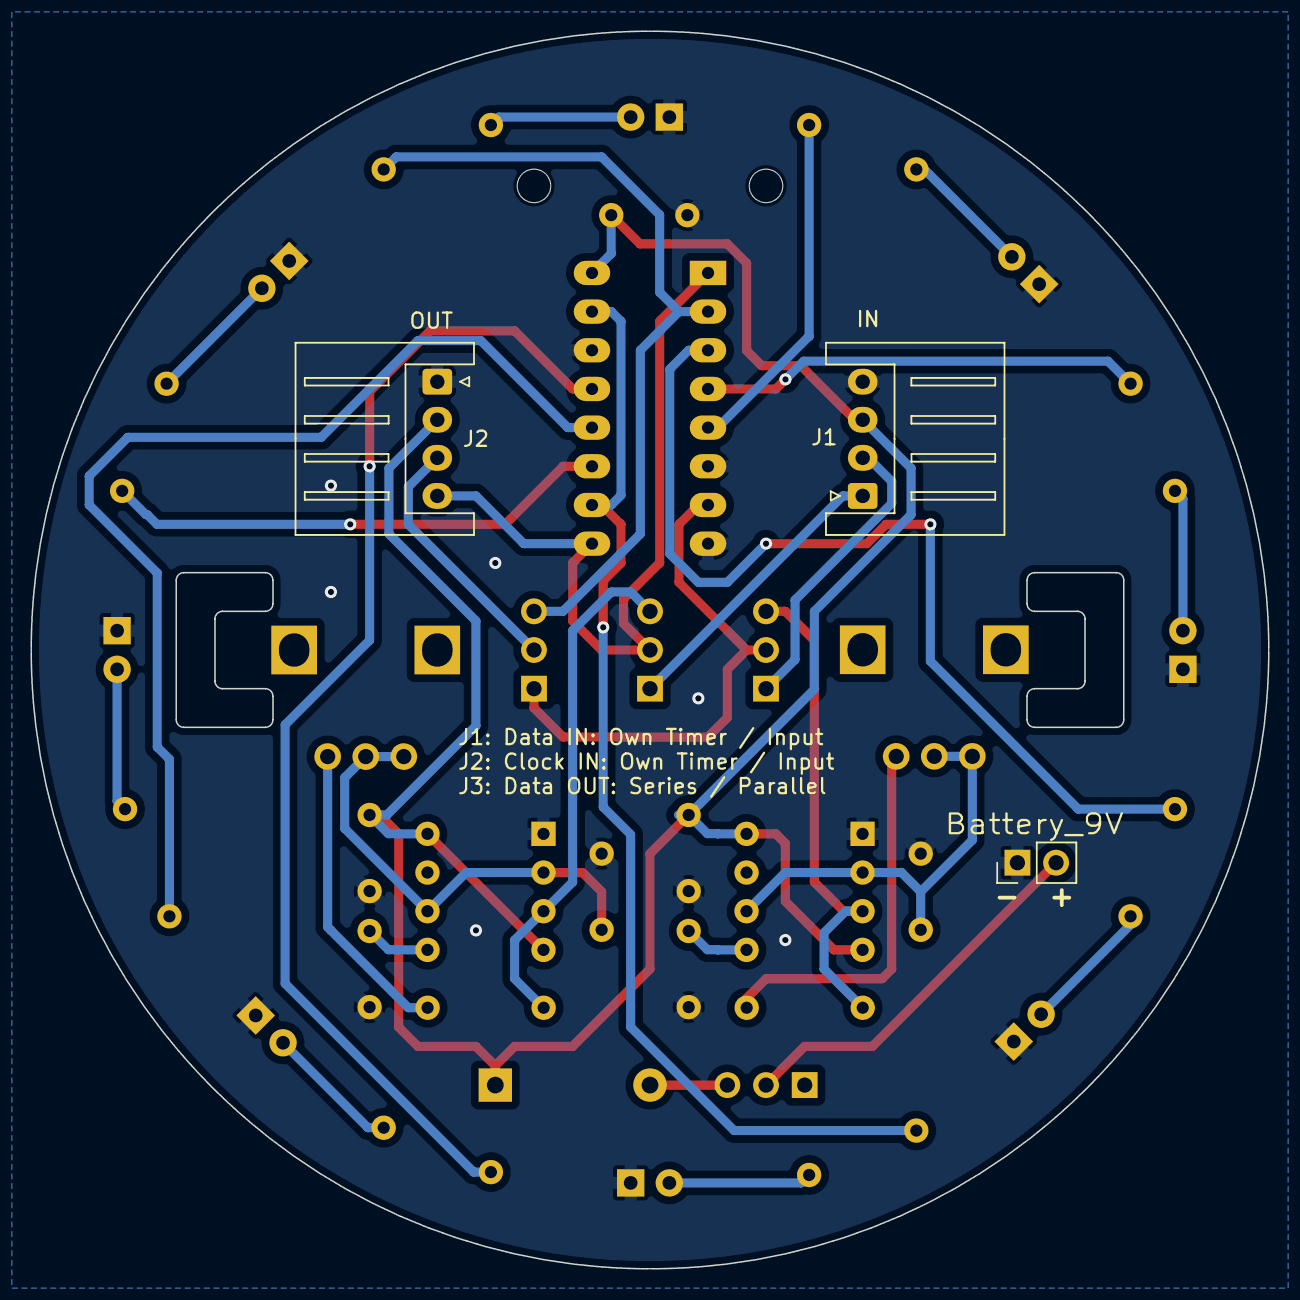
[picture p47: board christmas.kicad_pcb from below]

Board: 2 copper layers, 81.3 x 81.3 mm, 40 parts (3 on the bottom side), 33 nets.

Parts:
C1, C4, C5, C6, C7: 100n; C_Disc_D5.0mm_W2.5mm_P5.00mm
C2, C3: 4.7u; C_Disc_D5.0mm_W2.5mm_P5.00mm
D1, D2, D3, D4, D5, D6, D7, D8: LED; LED_D5.0mm
D9: 1N5817; D_DO-41_SOD81_P10.16mm_Horizontal
H1, H2: MountingHole; MountingHole_2.2mm_M2
J1, J2: Conn_01x04; JST_XH_S4B-XH-A_1x04_P2.50mm_Horizontal
J3: Battery_9V; PinHeader_1x02_P2.54mm_Vertical
JP1, JP2, JP3: Jumper_3_Open; PinHeader_1x03_P2.54mm_Vertical
ON/OFF1: Jumper_3_Open; PinHeader_1x03_P2.54mm_Vertical
R1, R3, R4, R5, R6, R7, R8, R9: 1.4k; R_Axial_DIN0207_L6.3mm_D2.5mm_P7.62mm_Horizontal
R2, R10: 10k; R_Axial_DIN0207_L6.3mm_D2.5mm_P7.62mm_Horizontal
RV1, RV2: 1M; RV09AF-40-ALPHA-POT
U1, U3: NE555P; DIP-8_W7.62mm
U2: 4015; DIP-16_W7.62mm_LongPads

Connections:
/Clk: J1.1, JP2.1 (A)
/Data: J1.2, JP1.1 (A)
/Timer1/Out: JP2.3 (B), R10.2, U3.3 (Q)
/Timer/Out: JP1.3 (B), R2.2, U1.3 (Q)
GND: C1.1, C2.1, C3.1, C4.1, C5.1, C6.1, C7.1, D1.1 (K), D2.1 (K), D3.1 (K), D4.1 (K), D5.1 (K), D6.1 (K), D7.1 (K), D8.1 (K), J1.4, J2.1, J3.1, U1.1 (GND), U2.6 (MR), U2.8 (Vss), U2.14 (MR), U3.1 (GND)
unnamed: D1.2 (A), R1.2
unnamed: D2.2 (A), R3.2
unnamed: D3.2 (A), R4.2
unnamed: D4.2 (A), R5.2
unnamed: D5.2 (A), R6.2
unnamed: D6.2 (A), R7.2
unnamed: D7.2 (A), R8.2
unnamed: D8.2 (A), R9.2
unnamed: D9.2 (A), ON/OFF1.3 (B)
unnamed: J2.3, JP3.2 (C)
unnamed: J2.4, JP2.2 (C), U2.1 (CP), U2.9 (CP)
unnamed: J3.2, ON/OFF1.2 (C)
unnamed: JP1.2 (C), JP3.1 (A), U2.7 (D)
unnamed: JP3.3 (B), R1.1, U2.2 (Q4)
unnamed: R2.1, RV1.3
unnamed: R10.1, RV2.3
unnamed: C4.2, U1.5 (CV)
unnamed: C3.2, RV1.1, RV1.2, U1.2 (TR), U1.6 (THR)
unnamed: R9.1, U2.5 (Q1)
unnamed: R8.1, U2.4 (Q2)
unnamed: R7.1, U2.3 (Q3)
unnamed: R6.1, U2.10 (Q4), U2.15 (D)
unnamed: R5.1, U2.13 (Q1)
unnamed: R4.1, U2.12 (Q2)
unnamed: R3.1, U2.11 (Q3)
unnamed: C6.2, U3.5 (CV)
unnamed: C2.2, RV2.1, RV2.2, U3.2 (TR), U3.6 (THR)
VCC: C1.2, C5.2, C7.2, D9.1 (K), J1.3, J2.2, U1.4 (R), U1.8 (VCC), U2.16 (Vdd), U3.4 (R), U3.8 (VCC)

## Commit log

2023-11-11 Add KiCad Sketch
    [christmas.kicad_sch]
2023-11-11 minor fixes
    [555Timer.kicad_sch, christmas.kicad_sch]
2023-11-12 added pictures
    [christmas.kicad_pcb, christmas.kicad_sch]
2023-11-12 added notebook and more pictures
    [christmas.kicad_sch]
2023-11-12 minor fixchanges
    [christmas.kicad_pcb, christmas.kicad_sch]
2023-11-13 major fixes
    [christmas.kicad_pcb, christmas.kicad_sch]
2023-11-13 generated and zipper JLC-PCB gerber files
    [christmas.kicad_pcb, christmas.kicad_sch]
2023-11-17 add fablab and vde logos, add rubber band battery holder cutouts
    [christmas.kicad_pcb]
2023-11-17 rewire board2board connector to match "same direction" cables
    [christmas.kicad_pcb, christmas.kicad_sch]
2023-11-29 Add to do for final pcb
2023-11-30 restructure components on board and implement ToDos from prototyping
    [555Timer.kicad_sch, christmas.kicad_pcb]
2023-12-01 update Shiftregister package
    [christmas.kicad_sch]
2023-12-01 Added frequency label on front silkscreen for poti
    [christmas-B_Cu.gbl, christmas-B_Mask.gbs, christmas-B_Paste.gbp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]
2023-12-01 Moved Frequency Label
    [christmas.kicad_pcb]
2023-12-01 switch Poti wiring, adjust to JLCPCB design rules
    [555Timer.kicad_sch, christmas.kicad_pcb]
2023-12-05 generate Gerber; FINAL ORDER VERSION
    [555Timer.kicad_sch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]
2023-12-12 update interactive BOM
2023-12-14 Update Assembly List.md
2023-12-14 Update README.md: add interactive BOM link
